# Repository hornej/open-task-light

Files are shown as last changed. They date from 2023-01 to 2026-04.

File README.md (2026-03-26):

# Open Task Light

Open Task Light is an ESP32-S3 task light project with firmware in
`code/open-task-light/` and hardware reference files at the repo root.

The current native firmware supports:
- capacitive touch controls for power, brightness, and color temperature
- separate warm and cool LED channels
- a WS2812 status LED
- optional LD2410B presence sensing
- optional Wi-Fi with native Home Assistant MQTT integration
- optional Apple Home support through native HomeKit
- optional Wi-Fi/SNTP-driven circadian color temperature control

The repo is organized as a top-level project folder with the firmware living
under `code/open-task-light/` and the hardware reference files at the root.

## Repo Layout

- `code/open-task-light/` firmware project
- `pcb/` PCB PDFs and fabrication reference files
- `LICENSE` project license

## Firmware

The active firmware project is in `code/open-task-light/`.

That subproject currently includes:
- ESP-IDF native firmware
- ESPHome configuration
- Arduino sketches
- checked-in defaults in `sdkconfig.defaults`

The ESP-IDF path is the main day-to-day firmware now. It defaults to an
offline local-light build. Wi-Fi, MQTT, HomeKit, and circadian are all
optional compile-time features.

Start with the detailed firmware README here:
- `code/open-task-light/README.md`

For local build profile notes, see:
- `code/open-task-light/local-config-profiles.md`

## Hardware Files

The `pcb/` folder currently contains:
- `DIYson.PDF`
- `DIYson_Fab.PDF`
- `Bill of Materials-DIYson.csv`

These are the board reference and fabrication outputs for the light.

For current build details and project updates, see the Basement Labs page:
- <https://www.basementlabs.net/open-task-light-2>

## Getting Started

If you are working on firmware:

```sh
cd code/open-task-light
```

Then follow the build and setup instructions in `code/open-task-light/README.md`.

Local build outputs such as `build/` and `sdkconfig` are generated there and
are intentionally not tracked in Git.

If you are working on hardware:
- review the PDFs in `pcb/`
- use the Basement Labs page for the current parts/build reference
- keep firmware pin mappings aligned with the board wiring

## Notes

The repo-root README is intentionally a project index. The detailed
day-to-day instructions for building, configuring, and using the embedded code
live in the nested firmware README.

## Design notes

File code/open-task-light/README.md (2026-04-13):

# Open Task Light

Firmware and configs for Open Task Light: an ESP32-S3 task light with
capacitive touch controls, warm/cool PWM channels, a WS2812 status LED, and
optional LD2410B presence sensing.

There are three supported build paths in this repo:
- ESP-IDF native firmware
- ESPHome configuration
- Arduino standalone sketch

The ESP-IDF firmware is the primary implementation and has the most complete
feature set.

## What The Light Does

Hardware and local behavior:
- 5 capacitive touch pads: power, brightness up, brightness down, cooler, warmer
- 2 PWM LED channels: warm white and cool white
- WS2812 status LED
- optional LD2410B presence sensor
- ambient light sensor
- LED NTC temperature sensor
- ESP32-S3 internal temperature monitoring

Optional connected behavior in the native firmware:
- shared Wi-Fi station support
- Home Assistant via native MQTT discovery
- Apple Home via native HomeKit
- Wi-Fi + SNTP circadian color temperature schedule

## Using The Light

### Touch controls

- Power pad:
  - tap toggles the light on or off
  - if the light is off, pressing power turns it on immediately
  - if you keep holding the power pad for about 3 seconds while turning on,
    the WS2812 status LED is enabled for that on-cycle
- Brightness up pad:
  - single tap raises brightness by 1%
  - double tap jumps to max brightness
  - hold ramps brightness upward smoothly
- Brightness down pad:
  - single tap lowers brightness by 1%
  - double tap jumps to the normal minimum brightness
  - hold ramps brightness downward
  - if you want the deepest dim range below the normal minimum, release and
    hold dim-down again after reaching minimum
- Cooler pad:
  - single tap shifts color temperature cooler
  - double tap jumps to maximum cool
  - hold ramps cooler
- Warmer pad:
  - single tap shifts color temperature warmer
  - double tap jumps to maximum warm
  - hold ramps warmer

### Presence behavior

If the LD2410B presence sensor is installed and enabled:
- occupancy turns on only after continuous presence for the configured on delay
- occupancy turns off only after continuous absence for the configured timeout
  (120 seconds by default)
- when occupancy clears, the light fades out
- when occupancy returns, the light fades back to its previous state

### Thermal behavior

- LED NTC temperature can clamp the maximum allowed brightness
- ESP32-S3 internal temperature is monitored separately as a chip-side failsafe
- the LED thermal limit is runtime-adjustable from Home Assistant when MQTT is enabled

## ESP-IDF Native Firmware

Source: `main/otl_main.c`

Quick start:

```sh
idf.py set-target esp32s3
idf.py menuconfig
idf.py build
idf.py -p PORT flash monitor
```

Checked-in defaults live in `sdkconfig.defaults`. Your `menuconfig` changes are
written to the local `sdkconfig` file, which is intentionally ignored so
Wi-Fi credentials and other machine-specific settings stay out of Git.

Default behavior:
- `sdkconfig.defaults` is an offline baseline
- Wi-Fi is off by default
- Home Assistant MQTT is off by default
- HomeKit is off by default
- circadian is off by default

That means a default build stays simple and local-only unless you explicitly
turn connected features on.

### Menuconfig areas

Under `Open Task Light`, the important sections are:

- `Serial logging`
  - app logs, periodic status, touch logs, calibration logs, PWM logs
- `Connectivity`
  - `Enable WiFi`
  - `Enable Home Assistant via MQTT`
  - `Enable Apple Home via HomeKit`
- `Presence sensor`
  - LD2410B enable, optional first-boot Bluetooth disable, distance thresholds,
    on/off delay, polling interval, UART sample stale timeout, UART
    auto-recovery interval
- `PWM`
  - non-overlapping warm/cool PWM
- `Circadian lighting`
  - Wi-Fi/SNTP-based circadian schedule and compile-time defaults

### Connectivity

The native firmware uses a shared Wi-Fi subsystem in `components/otl_net/`.
MQTT, HomeKit, and circadian all sit on top of that and are only compiled when
enabled.

Wi-Fi notes:
- Wi-Fi credentials are compile-time settings in `menuconfig`
- MQTT and HomeKit wait for Wi-Fi to connect before starting
- if Wi-Fi is disabled, none of the network stacks are initialized

### Home Assistant via MQTT

Enable in `menuconfig`:
- `Enable WiFi`
- `Enable Home Assistant via MQTT`

Then set:
- `MQTT broker URI`
- `MQTT username` and `MQTT password` if your broker requires auth
- optional discovery prefix, topic base, and device name

The firmware publishes a native Home Assistant MQTT device with:

- light entity
  - on/off
  - brightness
  - color temperature
- occupancy binary sensor when presence is enabled
- telemetry and diagnostics
  - radar OUT pin state
  - radar UART state
  - ambient lux
  - LED NTC temperature
  - ESP32-S3 internal temperature
  - thermal max brightness cap
  - thermal-limited status
  - Wi-Fi RSSI
  - last event
- runtime controls
  - LED thermal limit
  - radar occupancy off timeout
  - circadian lighting enable
  - circadian lighting coolest time
  - circadian lighting warmest time
  - circadian morning ramp duration
  - verbose diagnostics

Important behavior:
- the light state stays synchronized across touch, MQTT, presence behavior, and
  HomeKit when multiple integrations are enabled
- circadian lighting is runtime-toggleable from Home Assistant so it does not
  have to fight Adaptive Lighting or your own automations
- when the LD2410 UART stream goes stale, the radar presence/motion entities
  are marked unavailable in Home Assistant instead of falsely reading clear,
  while the radar UART diagnostic sensor reports `stale` or `no_response`
- the raw `Radar OUT` entity is published separately for Home Assistant
  visibility, but it is not used for the light auto-off logic
- the MQTT integration also publishes a structured event stream and a `Last Event`
  text sensor instead of mirroring raw serial logs

### Apple Home via HomeKit

Enable in `menuconfig`:
- `Enable WiFi`
- `Enable Apple Home via HomeKit`

Then set:
- `Accessory name`
- `Setup code`
- `Setup ID`

Pairing flow:
1. enter Wi-Fi credentials in `menuconfig`
2. build and flash the firmware
3. boot the light onto Wi-Fi
4. pair it in Apple Home using the configured setup code

Default development values:
- setup code: `111-22-333`
- setup ID: `OTL1`

Change those before handing a build to anyone else.

Current HomeKit surface:
- Lightbulb service
  - on/off
  - brightness
  - color temperature
- Occupancy Sensor service when presence is enabled

HomeKit intentionally stays narrower than Home Assistant. Diagnostics and
runtime tuning are exposed through MQTT/HA, not Apple Home.

### Circadian lighting

Enable in `menuconfig`:
- `Enable WiFi`
- `Enable circadian color temperature (WiFi + SNTP)`

Compile-time circadian settings:
- `Timezone (POSIX TZ string)`
- `SNTP server`
- `Update interval`
- `Coolest time (HH:MM)`
- `Warmest time (HH:MM)`
- `Morning cool ramp duration (minutes)`
- `Minimum cool ratio (%)`
- `Maximum cool ratio (%)`

Runtime behavior:
- the circadian engine computes a base warm/cool mix across the day
- after the warmest time, the light can hold maximum warmth overnight and only
  start cooling during the configurable morning ramp window before the coolest
  time
- temperature touch controls act as a user offset on top of that base
- if MQTT is enabled, Home Assistant can turn circadian lighting on or off at runtime
- if you want Home Assistant to own color temperature policy, disable circadian
  lighting and use your own automations or Adaptive Lighting

## Local Configuration Profiles

If you keep local config fragments outside Git, use:

```sh
./tools/use-local-profile.sh prod
./tools/use-local-profile.sh debug
```

That rebuilds `sdkconfig` from:
1. `sdkconfig.defaults`
2. `sdkconfig.local.shared`
3. `sdkconfig.local.<profile>`

See `local-config-profiles.md` for the expected pattern.

## ESPHome

Config: `esphome/open-task-light.yaml`

Quick start:

```sh
cp esphome/secrets.example.yaml esphome/secrets.yaml
esphome run esphome/open-task-light.yaml
```

Notes:
- `esphome/secrets.yaml` is intentionally ignored; keep your real Wi-Fi
  credentials there
- this path still exists for people who want an ESPHome-based build
- the native ESP-IDF firmware is the preferred path if you want the full touch
  behavior implemented in this repo

## Arduino

Sketch: `arduino/otl/otl.ino`

Optional radar test sketch: `arduino/LD2410B.ino`

Quick start:
1. Open `arduino/otl/otl.ino` in the Arduino IDE.
2. Select an ESP32-S3 board and install the `Adafruit NeoPixel` library.
3. Build and upload.

## Default Pin Map

| Function | GPIO | Notes |
| --- | --- | --- |
| Touch power | GPIO7 | T7 |
| Touch brightness up | GPIO8 | T8 |
| Touch brightness down | GPIO9 | T9 |
| Touch temp up | GPIO10 | T10 |
| Touch temp down | GPIO11 | T11 |
| PWM warm | GPIO35 | LEDC |
| PWM cool | GPIO36 | LEDC |
| WS2812 data | GPIO40 | Status LED |
| ALS (ambient light) | GPIO5 | ADC |
| NTC thermistor | GPIO16 | ADC |
| LD2410B OUT | GPIO15 | Alt: GPIO14 |
| LD2410B UART TX | GPIO43 | ESP32 TX -> radar RX |
| LD2410B UART RX | GPIO44 | ESP32 RX <- radar TX |

Adjust pins to match your board wiring as needed.

## Repo Layout

- `arduino/` Arduino sketches
- `components/esp-homekit-sdk/` vendored HomeKit SDK
- `components/otl_circadian/` shared circadian controller
- `components/otl_net/` shared Wi-Fi subsystem
- `esphome/` ESPHome configuration
- `managed_components/` ESP-IDF managed dependencies
- `main/` ESP-IDF firmware
- `sdkconfig.defaults` checked-in ESP-IDF defaults
- `tools/` helper scripts such as the local profile switcher and PWM scope watcher

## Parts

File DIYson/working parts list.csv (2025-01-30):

Part Name | Quantity | Category | Part Number | Link | European supplier | Note | Unit Cost (USD) | Total Cost (USD)
C-Clamp | 1 | Structure/Motion |  | https://amzn.to/3c4k5Et |  | Any small c-clamp will work | $15.10 | $15.10
GT2-2M Timing Belt (By the Foot) | 2 | Structure/Motion |  | https://openbuildspartstore.com/gt2-2m-timing-belt-by-the-foot/?ref=_2E7m4SXRIy8t | https://vslot-poland.com/timing-belt-GT2 |  | $2.49 | $4.98
Horizontal Rail (500mm) | 1 | Structure/Motion |  | https://openbuildspartstore.com/v-slot-20x20-linear-rail/?ref=_2E7m4SXRIy8t | https://vslot-poland.com/en_US/p/Aluminium-profile-2020-V-SLOT-Black-Anodized-250mm/38 |  | $3.29 | $3.29
Vertical Rail (500mm) | 1 | Structure/Motion |  | https://openbuildspartstore.com/v-slot-20x20-linear-rail/?ref=_2E7m4SXRIy8t | https://vslot-poland.com/en_US/p/Aluminium-profile-2020-V-SLOT-Black-Anodized-250mm/38 |  | $3.99 | $3.99
Xtreme Solid V Wheel Kit | 6 | Structure/Motion |  | https://openbuildspartstore.com/xtreme-solid-v-wheel-kit/?ref=_2E7m4SXRIy8t | https://vslot-poland.com/xtreme-solid-v-wheel-kit | Black Delrin or V-wheel kits can be substituted | $6.99 | $41.94
LED | 1 | Lighting | BXRV-TR-2750G-20A0-A-23 | https://www.digikey.com/en/products/detail/bridgelux/BXRV-TR-2750G-20A0-A-23/10279858 |  |  | $5.60 | $5.60
LED Holder | 1 | Lighting | 492 TYP L8 | https://led.cdiweb.com/products/detail/492typl8-bender-wirth/636069/
LED Socket | 1 | Lighting | C16142_HEKLA-SOCKET-K | https://www.mouser.com/ProductDetail/928-HEKLA16142 |  |  | $1.37 | $1.37
Lens | 1 | Lighting | CP16109_CARMEN-50-W-C | https://www.mouser.com/ProductDetail/928-CP16109 | https://eu.mouser.com/ProductDetail/928-CP16109 | Don't drop this, the tabs will break! | $4.98 | $4.98
48V AC/DC Power Supply | 1 | Lighting | SDI24-48-UD-P5 | https://www.mouser.com/ProductDetail/490-SDI24-48-UD-P5 |  |  | $18.94 | $18.94
AC Power Cord (US) | 1 | Lighting | Schurter 6010.5274 | https://www.mouser.com/ProductDetail/693-6010.5274
M3 10mm Standoffs | 2 |  |  | https://a.co/d/4ye4oMW
Heatpipe | 1 | Cooling | ATS-HP-F6L200S23W-294 | https://www.mouser.com/ProductDetail/984-HPF5L300S13W236 |  |  | $14.02 | $14.02
6mm Idler Pulley (Pack of 10) | 1 | Hardware |  | https://amzn.to/3AthhKy | https://nl.aliexpress.com/item/1005004778728908.html?mp=1 |  | $11.99 | $11.99
Aluminum Spacers (40mm) (Pack of 10) | 1 | Hardware |  | https://openbuildspartstore.com/aluminum-spacers-10-pack/?ref=_2E7m4SXRIy8t | https://nl.aliexpress.com/item/10000404234974.html?mp=1 | Connects vertical rail to base | $7.89 | $7.89
Aluminum Spacers (6mm) (Pack of 10) | 1 | Hardware |  | https://openbuildspartstore.com/aluminum-spacers-10-pack/?ref=_2E7m4SXRIy8t | https://nl.aliexpress.com/item/10000404234974.html?mp=1 | Four needed for mounting wheels | $3.39 | $3.39
Assorted metric screws and nuts | 1 | Hardware |  | https://amzn.to/3camT2N | https://nl.aliexpress.com/item/33033655207.html?mp=1 | Used to secure belt clips and pulleys (don't get this unless you need the m2 and m3 screws, it's one of the most expensive items on the list) | $32.98 | $32.98
Black-Oxide Alloy Steel Hex Drive Flat Head Screw | 1 | Hardware |  | https://www.mcmaster.com/91294A002/ |  | Used to secure drag chain and strain relief clip | $8.75 | $8.75
Black-Oxide 18-8 Stainless Steel Pan Head Phillips Screws | 1 | Hardware |  | https://www.mcmaster.com/95836A277/ |  | Used to attach PCB to LED cover | $10.52 | $10.52
Eccentric Spacer (6mm) | 2 | Hardware |  | https://openbuildspartstore.com/eccentric-spacer/?ref=_2E7m4SXRIy8t |  |  | $1.99 | $3.98
Low Profile M5 Screws (15mm) (Pack of 10) | 1 | Hardware |  | https://openbuildspartstore.com/low-profile-screws-m5-10-pack/?ref=_2E7m4SXRIy8t | https://nl.aliexpress.com/item/1005003411992910.html?mp=1 | 4 needed to attach base and pulley assembly to vertical rail. One needed to tension the base | $1.19 | $1.19
Low Profile M5 Screws (25mm) (Pack of 10) | 1 | Hardware |  | https://openbuildspartstore.com/low-profile-screws-m5-10-pack/?ref=_2E7m4SXRIy8t | https://nl.aliexpress.com/item/1005003411992910.html?mp=1 | For mountng wheels to carriage and counterweight | $1.39 | $1.39
Low Profile Screw (Pack of 10) | 1 | Hardware |  | https://www.mcmaster.com/97710A129/ |  | Used to mount the LED assembly to the horizontal arm | $10.00 | $10.00
M3 Nyloc Nuts (Pack of 50) | 1 | Hardware |  | https://amzn.to/3Qxgn5a | https://nl.aliexpress.com/item/33030388407.html?mp=1 | Used in pulley assembly | $6.99 | $6.99
M5 Nyloc Nuts (Pack of 50) | 1 | Hardware |  | https://amzn.to/3T3DINM | https://nl.aliexpress.com/item/33030388407.html?mp=1 | Used in base | $6.49 | $6.49
Super Low Profile Nyloc Nut (pack of 4) | 2 | Hardware |  | https://www.getfpv.com/m5-black-aluminum-shallow-flange-lock-nut-set-of-4-cw.html | https://www.buildyourowndrone.co.uk/lumenier-m5-black-aluminum-low-profile-lock-nut-set-of-4-cw | For mountng wheels to carriage and counterweight | $4.99 | $9.98

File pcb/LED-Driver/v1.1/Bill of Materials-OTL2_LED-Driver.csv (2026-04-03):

Designator | Supplier Part Number | Supplier | Quantity | Comment | Manufacturer | Manufacturer Part Number | Footprint | Description | Case/Package
C7 | C185774 | LCSC | 1 | 10uF | TORCH | CA45-A-16V-10µF-K | CAPMP3216X180N | 10uF 16V 2O@100kHz ±10% CASE-A-3216 Tantalum Capacitors ROHS
C15 | C15195 | LCSC | 1 | 10nF | Samsung Electro-Mechanics | CL05B103KB5NNNC | CAP_0402_SK | 50V 10nF X7R ±10% 0402 Multilayer Ceramic Capacitors MLCC - SMD/SMT ROHS | 0402
C18 | C28233 | LCSC | 1 | 100nF | Samsung Electro-Mechanics | CL21B104KCFNNNE | CAP_0805_SK | 100V 100nF X7R ±10% 0805 Multilayer Ceramic Capacitors MLCC - SMD/SMT ROHS | 0805
C23 | C19702 | LCSC | 1 | 10uF | Samsung Electro-Mechanics | CL10A106KP8NNNC | CAP_0603_SK | 10V 10uF X5R ±10% 0603 Multilayer Ceramic Capacitors MLCC - SMD/SMT ROHS | 0603
CONN1 | C5187472 | LCSC | 1 | TYPE-C 16P QTWT | SHOU HAN | TYPE-C 16P QTWT | CONN_USBC_C5187472 | 3A 1 Surface Mount 16P Female -25?~+85? Type-C SMD USB Connectors ROHS USB-C
CONN2 |  |  | 1 | 781710002 | Molex | 78171-0002 | MOLEX_0781710002 | Pico-EZmate Wire-to-Board Header Vertical Housing Height 1.55mm with Side Friction Locks 2 Circuits
CONN3 | C5852764 | LCSC | 1 | 009276004021106 | KYOCERA AVX | 009276004021106 | CONN_009276004021006_AVX | Rectangular Power Connector, 4 Contact(s), Female, Surface Mount Terminal
CONN4 | C724177 | LCSC | 1 | Pico-EZmate | Molex | 78171-0005 | CONN_781710000-SD_05_MOL | Pico-EZmate Wire-to-Board Header Vertical Housing Height 1.55mm with Side Friction Locks 5 Circuits
D8 | C134996 | LCSC | 1 | 54V | Diodes | SMAJ54A-13-F | DIOD-SMA-2_V | SMAJ Series 54 V 400 W Surface Mount Uni-Directional TVS Diode - DO-214AC | SMA
L3 | C92942 | LCSC | 1 | 33uH | Taiyo Yuden | NR6045T330M | NR6045 | FIXED IND 33UH 1.4A 188.5 MOHM | Nonstandard
R5 | C144804 | LCSC | 1 | 118k | Yageo | AC0402FR-07118KL | RES_0402 | Res Thick Film 0402 118K Ohm 1% 0.063W(1/16W) ±100ppm/C Pad SMD Automotive T/R | 0402
R6 | C163478 | LCSC | 1 | 22.1k | Yageo | RC0402FR-0722K1L | RES_0402 | SMD Chip Resistor, 22.1 kOhm, ï¿½ 1%, 62.5 mW, 0402 [1005 Metric], Thick Film, General Purpose | 0402
R15 | C26083 | LCSC | 1 | 1M | Uni-Royal | 0402WGF1004TCE | RES_0402 | Res Thick Film 0402 1M Ohm 1% 0.063W(1/16W) ±100ppm/C Pad SMD T/R
R24 | C25764 | LCSC | 1 | 200k | Royal Ohm | 0402WGF2003TCE | RES_0402 | Royal Ohm 0402WGF2003TCE 200K 1% 1/16W 0402 Thick Film Chip Resistor
R25 | C17888 | LCSC | 1 | 0 | Royal Ohm | 1206W4F0000T5E | RES_1206 | Thick Film Resistors - SMD RMC 1206 1/4W 1% T/R-5000
R31 | C25897 | LCSC | 1 | 49.9k | Royal Ohm | 0402WGF4992TCE | RES_0402 | Thick Film Resistors - SMD RMC 0402 1/16W 1% T/R-10000
R32 | C11457 | LCSC | 1 | 3.24k | Royal Ohm | 0402WGF3241TCE | RES_0402 | Thick Film Resistors - SMD RMC 0402 1/16W 1% T/R-10000
R34 | C23254 | LCSC | 1 | 82k | Royal Ohm | 0603WAF8202T5E | RES_0603 | -55?~+155? 100mW 75V 82kO Thick Film Resistor ±1% ±100ppm/? 0603 Chip Resistor - Surface Mount ROHS
R37 | C11702 | LCSC | 1 | 1k | Royal Ohm | 0402WGF1001TCE | RES_0402 | 62.5mW Thick Film Resistors 50V ±100ppm/? ±1% 1kO 0402 Chip Resistor - Surface Mount ROHS
U1 | C3013941 | LCSC | 1 | ESP32-S3-MINI-1-N4R2 | Espressif Systems | ESP32-S3-MINI-1-N4R2 | ESP32-S3-MINI-1-N4R2_noVias | On-board PCB antenna SMD WiFi Modules ROHS
U4 | C21260865 | LCSC | 1 | LMR51606XDBVR | Texas Instruments | LMR51606XDBVR | SOT-23-6 | SIMPLE SWITCHER® power converter with 4.5V-to-65V 0.6A synchronous buck and 25µA quiescent current 6-SOT-23 -40 to 150 | SOT-23
U5 | C6186 | LCSC | 1 | AMS1117-3.3_AMS | Advanced Monolithic Systems | AMS1117-3.3 | DCY0004A_L | -40?~+125? 0.003%Vout 1 1.1V@(800mA) 16V 1A 3.3V 5mA 72dB@(120Hz) Fixed Over Current Protection?Over Temperature Protection Positive SOT-223 Voltage Regulators - Linear, Low Drop Out (LDO) Regulators ROHS
U6 |  |  | 1 | ALS-PT19-315C/L177/TR8 | Everlight | ALS-PT19-315C/L177/TR8 | XDCR_ALS-PT19-315C/L177/TR8 | Light to Current Ambient Light Sensor Digital 3.3V/5V 2-Pin SMD T/R | SMD/SMT
U7 | C168856 | LCSC | 1 | 74LVC1T45W6-7 | Diodes | 74LVC1T45W6-7 | SOT-23-6 | 74LVC Series 5.5 V 3-State SMT Single Bit Dual Supply Transceiver - SOT-26 | SOT-23-6
U8 | C965557 | LCSC | 1 | WS2812B-4020 | Worldsemi | WS2812B-4020 | WS2812B-4020 | SMD,2x4mm RGB LEDs(Built-in IC) ROHS
C19, C20 | C513710 | LCSC | 2 | 220nF | Yageo | CC0805KKX7R0BB224 | CAP_0805_SK | CAP CER 0.22UF 100V X7R 0805 | 0805
CONN5, CONN6 |  |  | 2 | 781710002 | Molex | 78171-0002 | MOLEX_0781710002_HANDSOLDER_NTC | Pico-EZmate Wire-to-Board Header Vertical Housing Height 1.55mm with Side Friction Locks 2 Circuits
L1, L2 | C5291902 | LCSC | 2 | 120uH | CENKER | CKCS8040-120uH/M | IND_8x8x4 | 950mA 120uH 334mO 1.12A Magnetic Shielded Inductor ±20% SMD,8x8mm Fixed Inductors RoHS
R1, R3 | C25889 | LCSC | 2 | 3.01k | Royal Ohm | 0402WGF3011TCE | RES_0402 | Thick Film Resistors - SMD RMC 0402 1/16W 1% T/R-10000
R2, R4 | C25765 | LCSC | 2 | 20k | UNI-ROYAL | 0402WGF2002TCE | RES_0402 | 20kO ±1% 62.5mW 0402 Thick Film Resistor
R13, R14 | C25905 | LCSC | 2 | 5.1k | Uni-Royal | 0402WGF5101TCE | RES_0402 | Res Thick Film 0402 5.1K Ohm 1% 0.063W(1/16W) ±100ppm/C Pad SMD T/R
R28, R29 | C858641 | LCSC | 2 | 0.1 | Yageo Group | PT0603FR-7W0R1L | RES_0603 | Res Thick Film 0603 0.1 Ohm 1% 0.2W(1/5W) ±200ppm/C Pad SMD Automotive T/R | 0603
SW8, SW9 | C393942 | LCSC | 2 | TS24CA | SHOU HAN | TS24CA | SW_TS24CA | 1.8mm 3.5mm Rectangle button 50mA Horizontal attachment 4.55mm SPST 12V SMD Tactile Switches ROHS spst
U2, U3 | C114277 | LCSC | 2 | TPS92511DDAR | Texas Instruments | TPS92511DDAR | VREG_LM5017MR/NOPB | 500mA 30W Anode Capable constant current buck LED Dvr 8-SO PowerPAD -40 to 125 | HSOP
C1, C3, C5 | C237304 | LCSC | 3 | 4.7uF | Murata | GRM31CC72A475KE11L | CAP_1206_SK | 100V 4.7uF X7S ±10% 1206 Multilayer Ceramic Capacitors MLCC - SMD/SMT ROHS | 1206
C8, C9, C11 | C45783, C98190 | LCSC | 3 | 22uF | Samsung Electro-Mechanics, Samsung | CL21A226MAQNNNE, CL21A226MOQNNNE | CAP_0805_SK | Multilayer Ceramic Capacitor, 22 uF, 25 V, ± 20%, X5R, 0805 [2012 Metric], Cap Ceramic 22uF 16V X5R 20% SMD 0805 85°C Embossed Plastic T/R | 0805
D1, D2, D3 | C77393 | LCSC | 3 | SS2PH10-M3/84A | Vishay | SS2PH10-M3/84A | DIOD_DO-220AA (SMP) | Rectifier Diode, Schottky, 1 Phase, 1 Element, 2A, 100V V(RRM), Silicon, DO-220AA | DO-220AA
D5, D6, D7 | C5246195 | LCSC | 3 | LESD5D5.0CT1G_Leiditech | Leiditech | LESD5D5.0CT1G | DIOD_SOD523 | ESD DIODE 5VWM 12VC SOD-523 bi-directional
R7, R8, R35 | C25900 | LCSC | 3 | 4.7k | Royal Ohm | 0402WGF4701TCE | RES_0402 | Res Thick Film 0402 4.7K Ohm 1% 0.063W(1/16W) ±100ppm/C Pad SMD T/R
R16, R23, R26, R27 | C137962 | LCSC | 4 | 4.7 | Yageo | RC0402FR-074R7L | RES_0402 | SMD Chip Resistor 4.7 Ohm ½ 1% 62.5 Mw 0402 [1005 Metric] Thick Film General Purpose | 0402
C2, C4, C12, C16, C17 | C52923 | LCSC | 5 | 1uF | Samsung | CL05A105KA5NQNC | CAP_0402_SK | 1 µF ±10% 25V Ceramic Capacitor X5R 0402 (1005 Metric) | 0402
R9, R10, R17, R33, R36 | C25744 | LCSC | 5 | 10k | Uni-Royal | 0402WGF1002TCE | RES_0402 | Res Thick Film 0402 10K Ohm 1% 0.063W(1/16W) ±100ppm/C Pad SMD T/R
R11, R12, R30, R38, R39 | C106231 | LCSC | 5 | 0 | Yageo | RC0402FR-070RL | RES_0402 | Res Thick Film 0402 0 Ohm Molded SMD SMD Paper T/R | 0402
R18, R19, R20, R21, R22 | C276273 | LCSC | 5 | 510 | Yageo | RC0402FR-07510RL | RES_0402 | SMD Chip Resistor, 510 Ohm, ± 1%, 63 mW, 0402 [1005 Metric], Thick Film, General Purpose | 0402
C6, C10, C13, C14, C21, C22 | C1525 | LCSC | 6 | 100nF | Samsung Electro-Mechanics | CL05B104KO5NNNC | CAP_0402_SK | 16V 100nF X7R ±10% 0402 Multilayer Ceramic Capacitors MLCC - SMD/SMT ROHS | 0402

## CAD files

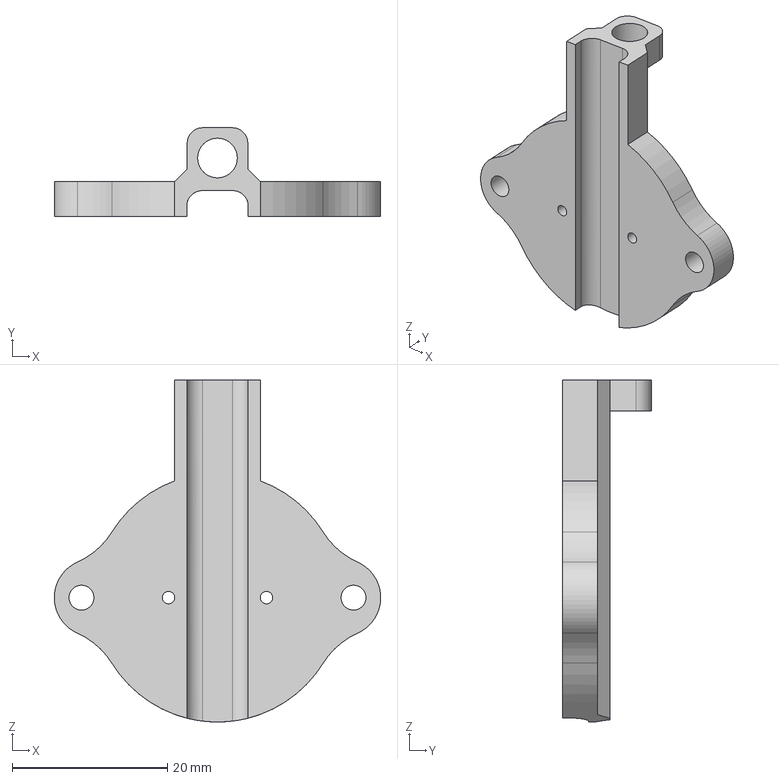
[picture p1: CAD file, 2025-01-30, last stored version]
DIYson/Mechanical/STEP/Lighting Assembly Mount.step
42.0 x 11.4 x 44.0 mm

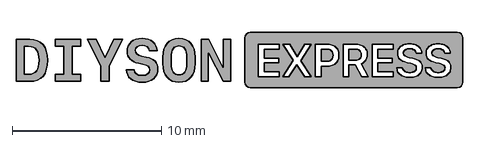
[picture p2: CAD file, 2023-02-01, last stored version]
DIYson Express/Assets/express logo expanded.dxf
29.9 x 3.70 mm

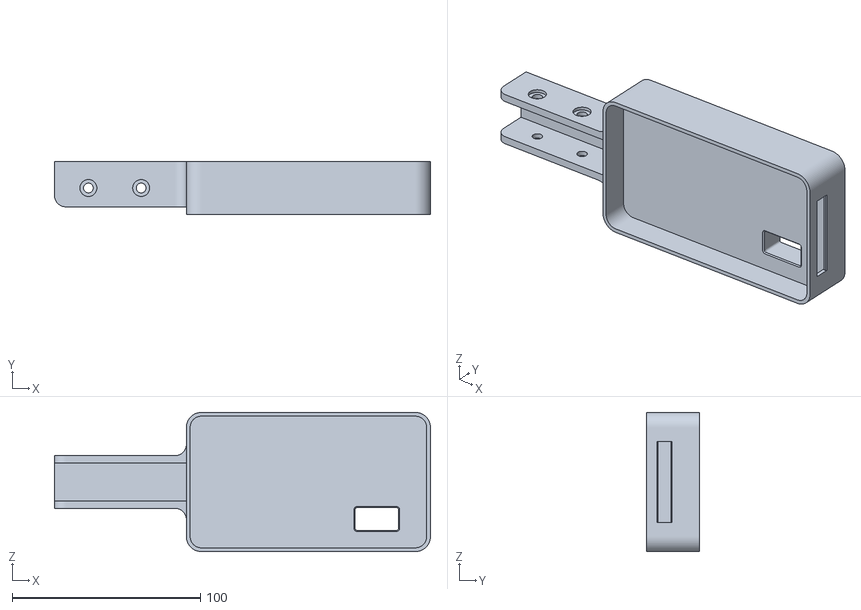
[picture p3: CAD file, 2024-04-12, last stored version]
DIYson Express/Community-Made Alternatives/brukhabtu - LED Holder (LumeCube)/Lume Cube Bicolor Panel.stl
199.6 x 28.0 x 73.9

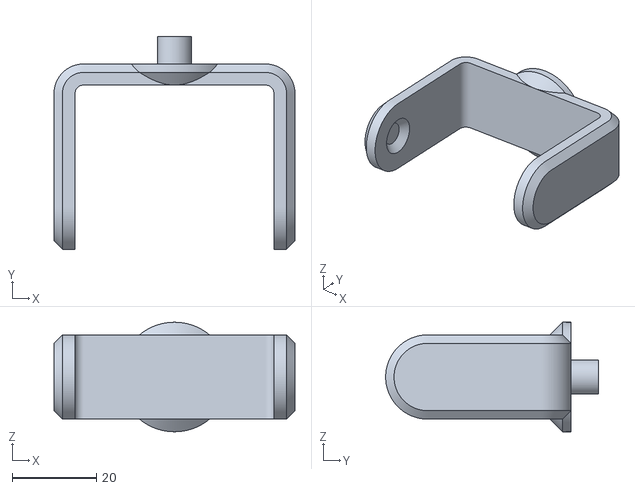
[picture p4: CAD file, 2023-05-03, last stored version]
DIYson Express/Community-Made Alternatives/jfuchs - Gimbal/Outer ring.stl
57.2 x 50.5 x 26.0

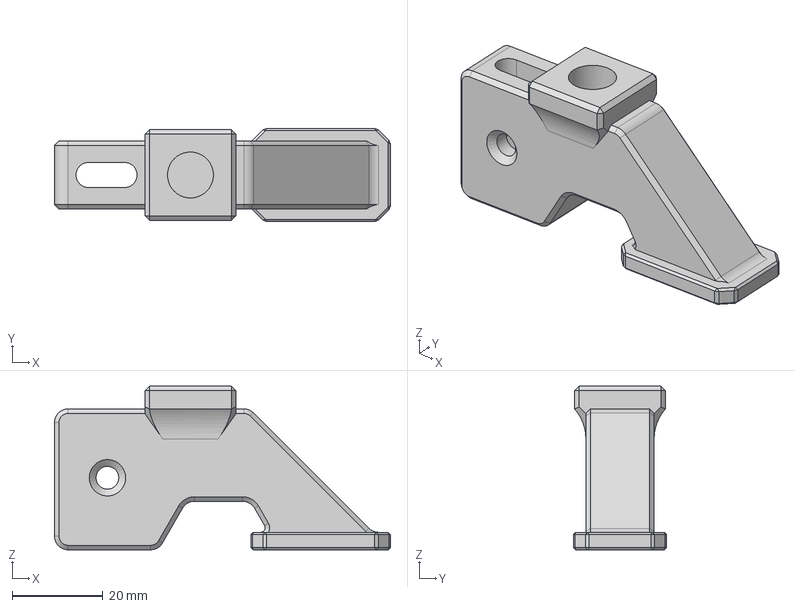
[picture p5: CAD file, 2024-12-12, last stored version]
DIYson Express/Community-Made Alternatives/robocat-studios - Base for IRWIN QUICK-GRIP/Base for IRWIN QUICK-GRIP.step
73.9 x 20.5 x 36.0 mm

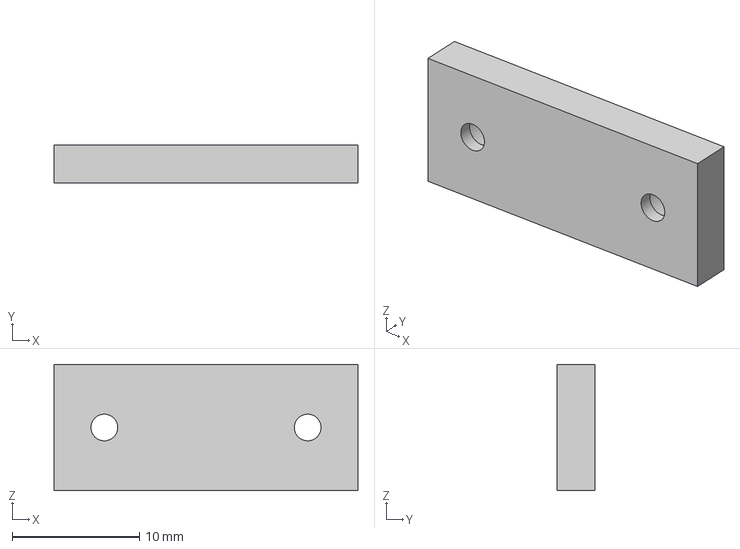
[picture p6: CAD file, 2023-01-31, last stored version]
DIYson Express/Printed Parts/STEP/Coutnterweight Lid.step
23.9 x 3.00 x 9.92 mm

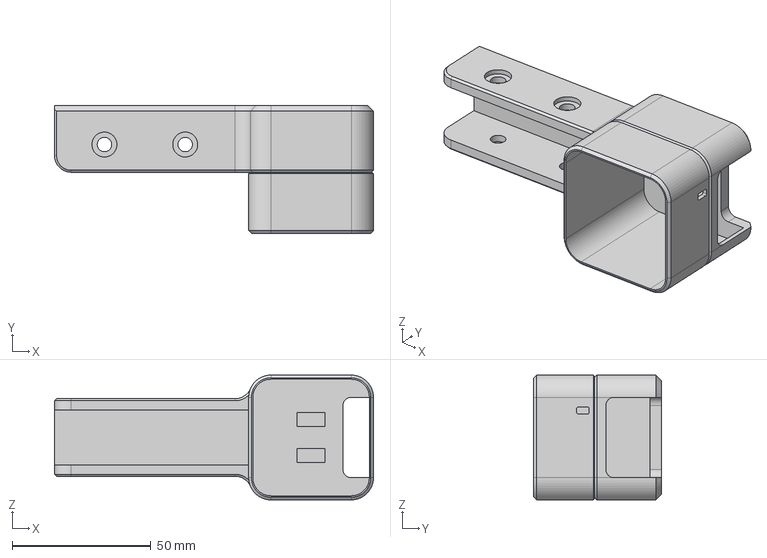
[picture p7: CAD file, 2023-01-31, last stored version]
DIYson Express/Printed Parts/STEP/LED Holder Options/Ulanzi L2.step
115.0 x 46.0 x 45.0 mm

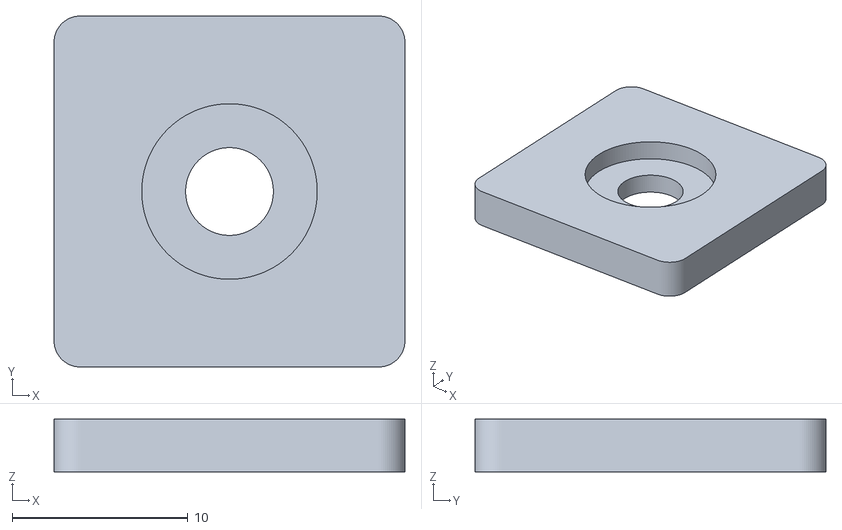
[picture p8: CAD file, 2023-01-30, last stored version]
DIYson Express/Printed Parts/STL/End Cap (optional).stl
20.0 x 20.0 x 3.00

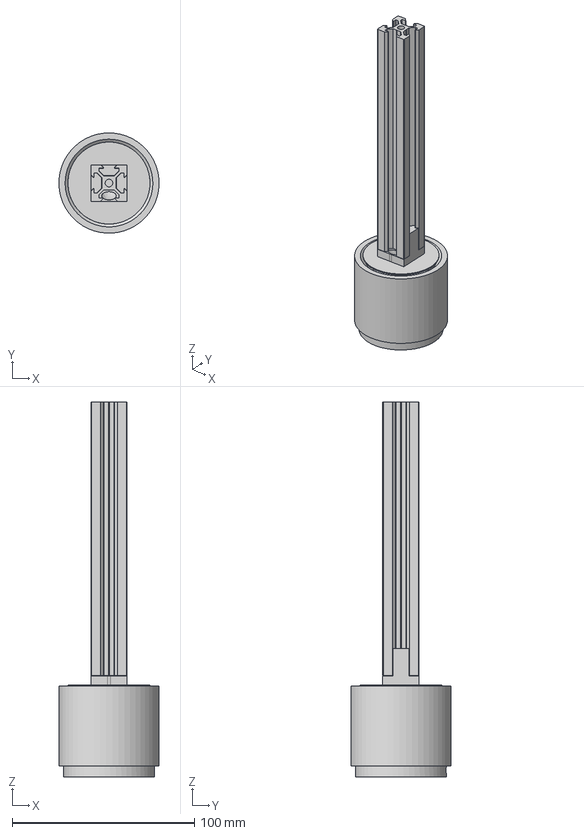
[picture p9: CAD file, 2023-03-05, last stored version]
DIYson/Community-Made Alternatives/Tim - Base/Base.step
55.0 x 55.0 x 205.7 mm
Body_Kugel_einzeln (1) x 8
Body_Innenring (1)
Body_Aussenring (1)
20x20Rail
SlipRing
BoxUpper
BoxLower
Spacer
RailConnector

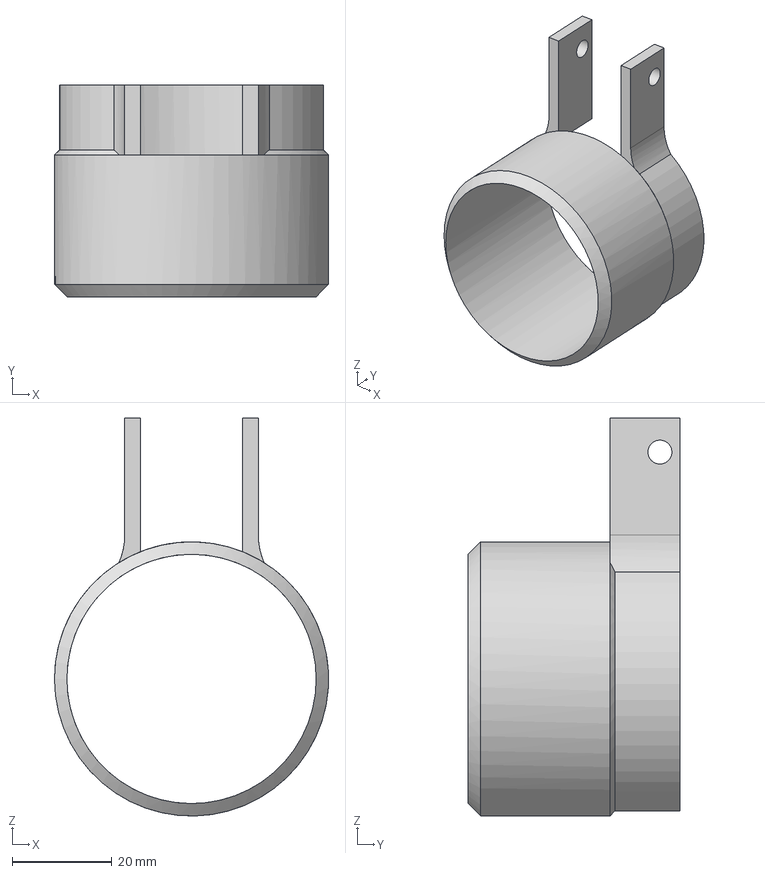
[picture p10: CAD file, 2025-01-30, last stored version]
DIYson/Mechanical/STEP/LED Cover - Bottom.step
55.0 x 42.5 x 79.8 mm

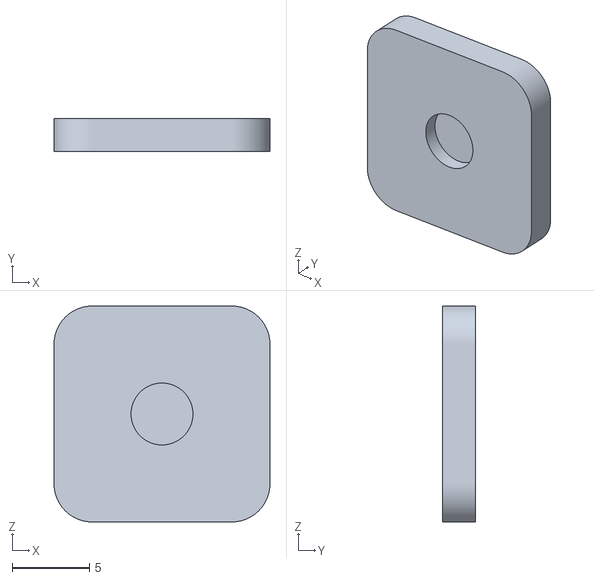
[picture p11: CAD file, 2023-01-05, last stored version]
DIYson/Mechanical/STL/Increase Brightness Button.stl
13.9 x 2.10 x 13.9

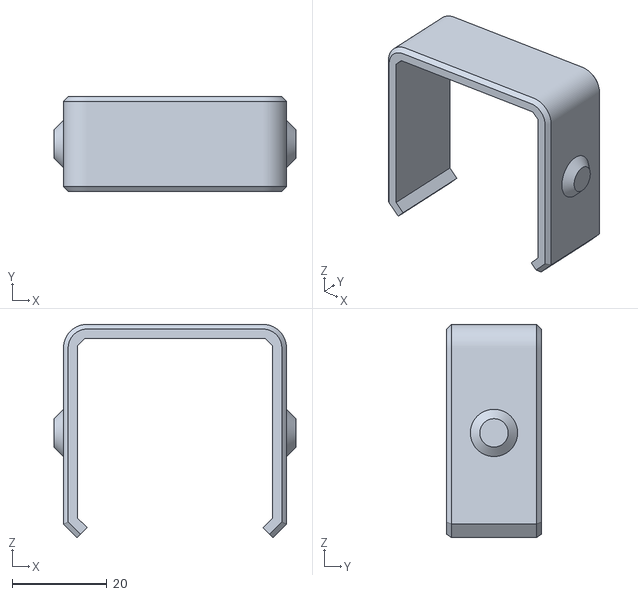
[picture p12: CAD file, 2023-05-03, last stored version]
DIYson Express/Community-Made Alternatives/jfuchs - Gimbal/Inner ring.stl
51.2 x 20.0 x 45.1

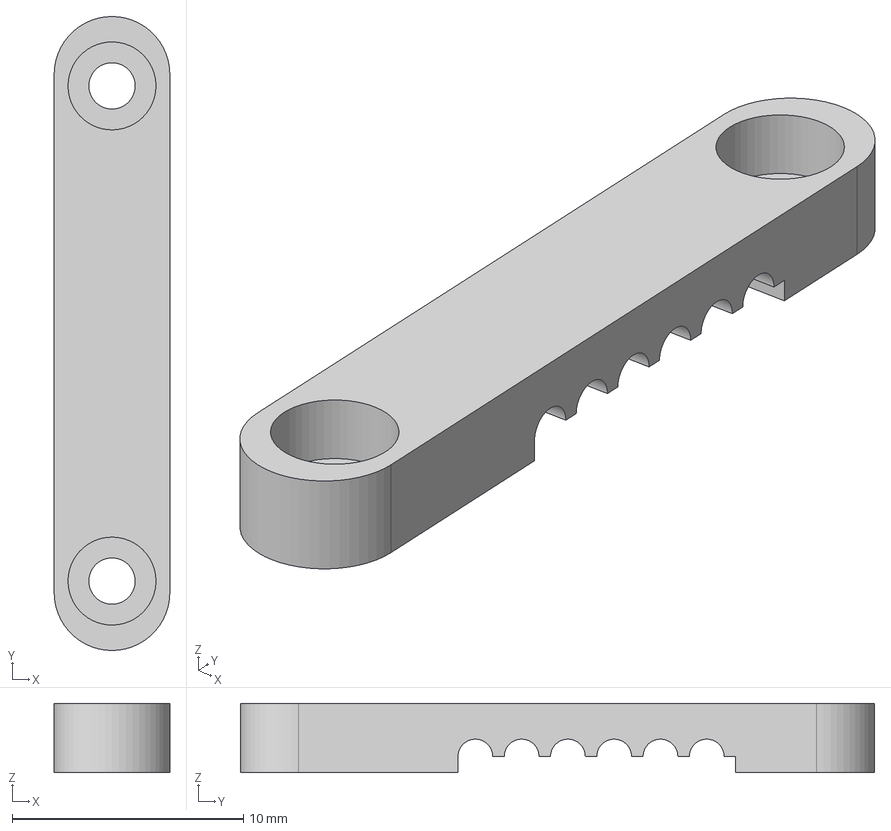
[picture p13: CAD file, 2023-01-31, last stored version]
DIYson Express/Printed Parts/STEP/Carriage Belt Clip.step
5.00 x 27.4 x 3.00 mm

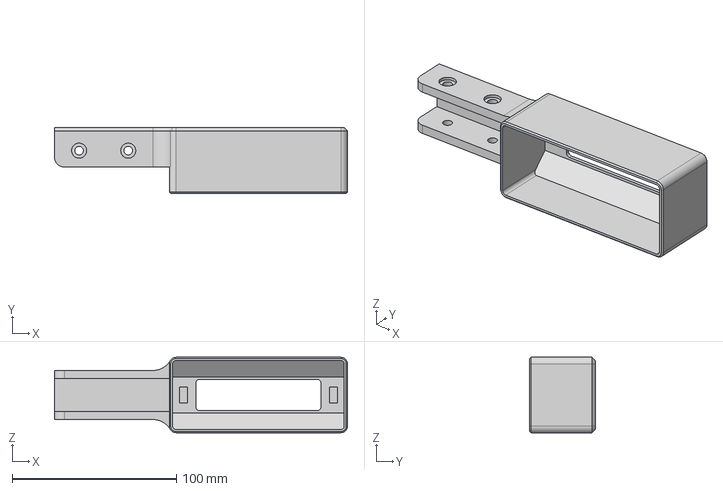
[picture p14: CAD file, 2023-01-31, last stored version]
DIYson Express/Printed Parts/STEP/LED Holder Options/Ulanzi Wand.step
178.5 x 40.0 x 46.0 mm

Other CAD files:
DIYson Express/Community-Made Alternatives/brukhabtu - LED Holder (LumeCube)/LEDHolderLumeCube.step
DIYson Express/Printed Parts/STL/Charging Base (optional).stl
DIYson/Mechanical/STEP/LED Cover - Top.step
DIYson/Mechanical/STL/Decrease Brightness Button.stl
DIYson Express/Community-Made Alternatives/jfuchs - Gimbal/Extrusion bracket.stl
DIYson Express/Community-Made Alternatives/robocat-studios - Base for IRWIN QUICK-GRIP/Base for IRWIN QUICK-GRIP.3mf
DIYson Express/Fan-Made Alternatives/jfuchs - Gimbal/Extrusion bracket.stl
DIYson Express/Printed Parts/F3D/Base.f3d
DIYson Express/Printed Parts/F3D/Desk Mount.f3d
DIYson Express/Printed Parts/F3D/LED Holder Starter Template.f3z
DIYson Express/Printed Parts/STEP/Base.step
DIYson Express/Printed Parts/STEP/Carriage.step
DIYson Express/Printed Parts/STEP/Chargine Base.step
DIYson Express/Printed Parts/STEP/Counterweight Belt Clip.step
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

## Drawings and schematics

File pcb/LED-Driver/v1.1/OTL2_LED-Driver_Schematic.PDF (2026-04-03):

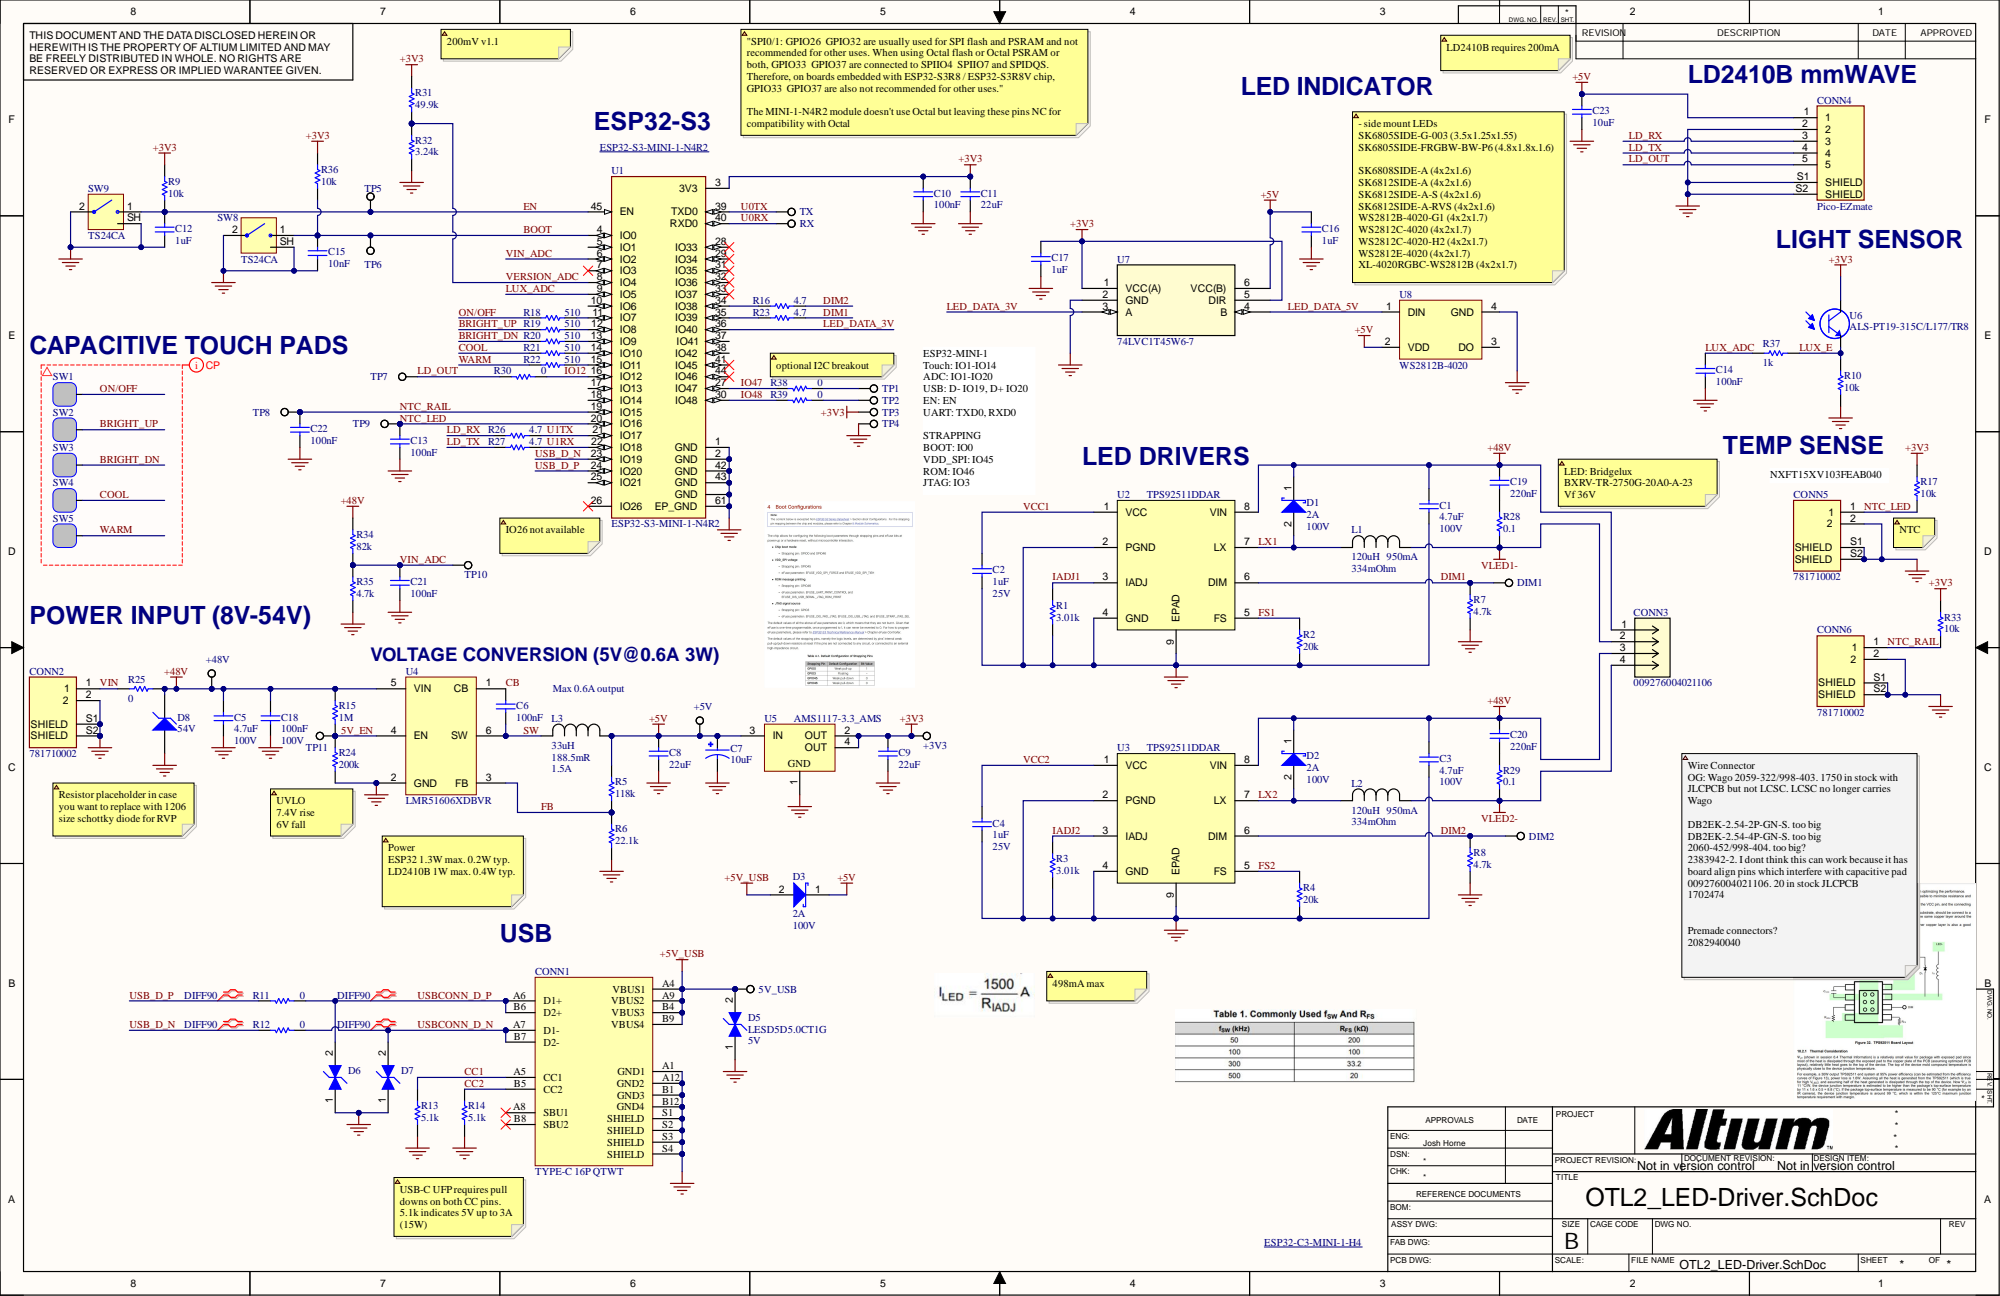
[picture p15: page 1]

DWG . N O . | R E V | * . S H T.

T H IS DOC U MEN T AN D T HE D ATA D ISCLOSED HEREI N OR HEREW I T H IS T HE PROPER TY OF ALT I U M LI M I TED AN D M AY BE F REELY D IST R IBU TED I N W HOLE. NO R IGH TS ARE RESERVED OR EXPRESS OR I MPLIED WARAN TEE GIVEN . | | REVISI O | N DESC R IPT I O N | DAT E | APPR OVED

sed for SPI flas

REV. SHT. DWG. NO.

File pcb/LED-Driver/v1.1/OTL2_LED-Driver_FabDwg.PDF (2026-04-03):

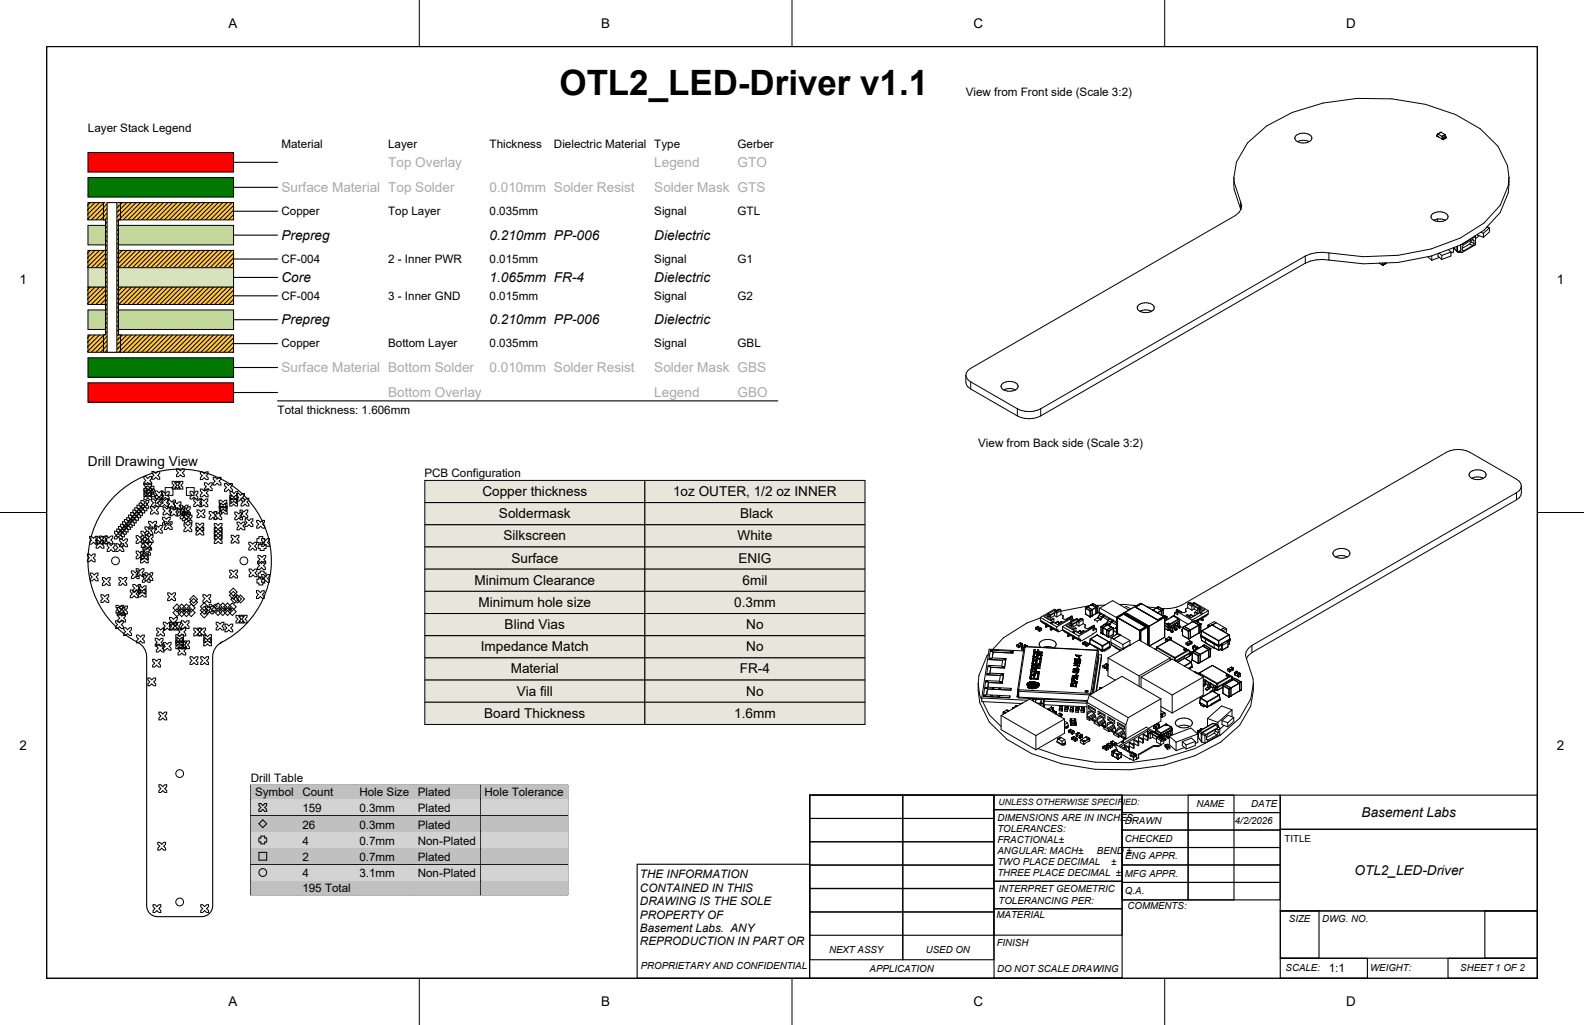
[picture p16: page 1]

View from Front side (Scale 3:2)

View from Back side (Scale 3:2)

UNLESS OTHERWISE SPECIFIED: | | NAME | DATE | Basement Labs
DIMENSIONS ARE IN INCHES TOLERANCES: FRACTIONAL± ANGULAR: MACH± BEND ± TWO PLACE DECIMAL ± THREE PLACE DECIMAL ± | DRAWN | | 4/2/2026

CHECKED | | | TITLE OTL2_LED-Driver
ENG APPR.

THE INFORMATION CONTAINED IN THIS DRAWING IS THE SOLE PROPERTY OF Basement Labs. ANY REPRODUCTION IN PART OR PROPRIETARY AND CONFIDENTIAL | | | MFG APPR.

INTERPRET GEOMETRIC TOLERANCING PER: | Q.A.

MATERIAL | | SIZE | DWG. NO.

NEXT ASSY | USED ON | FINISH DO NOT SCALE DRAWING

APPLICATION | | | 1:1

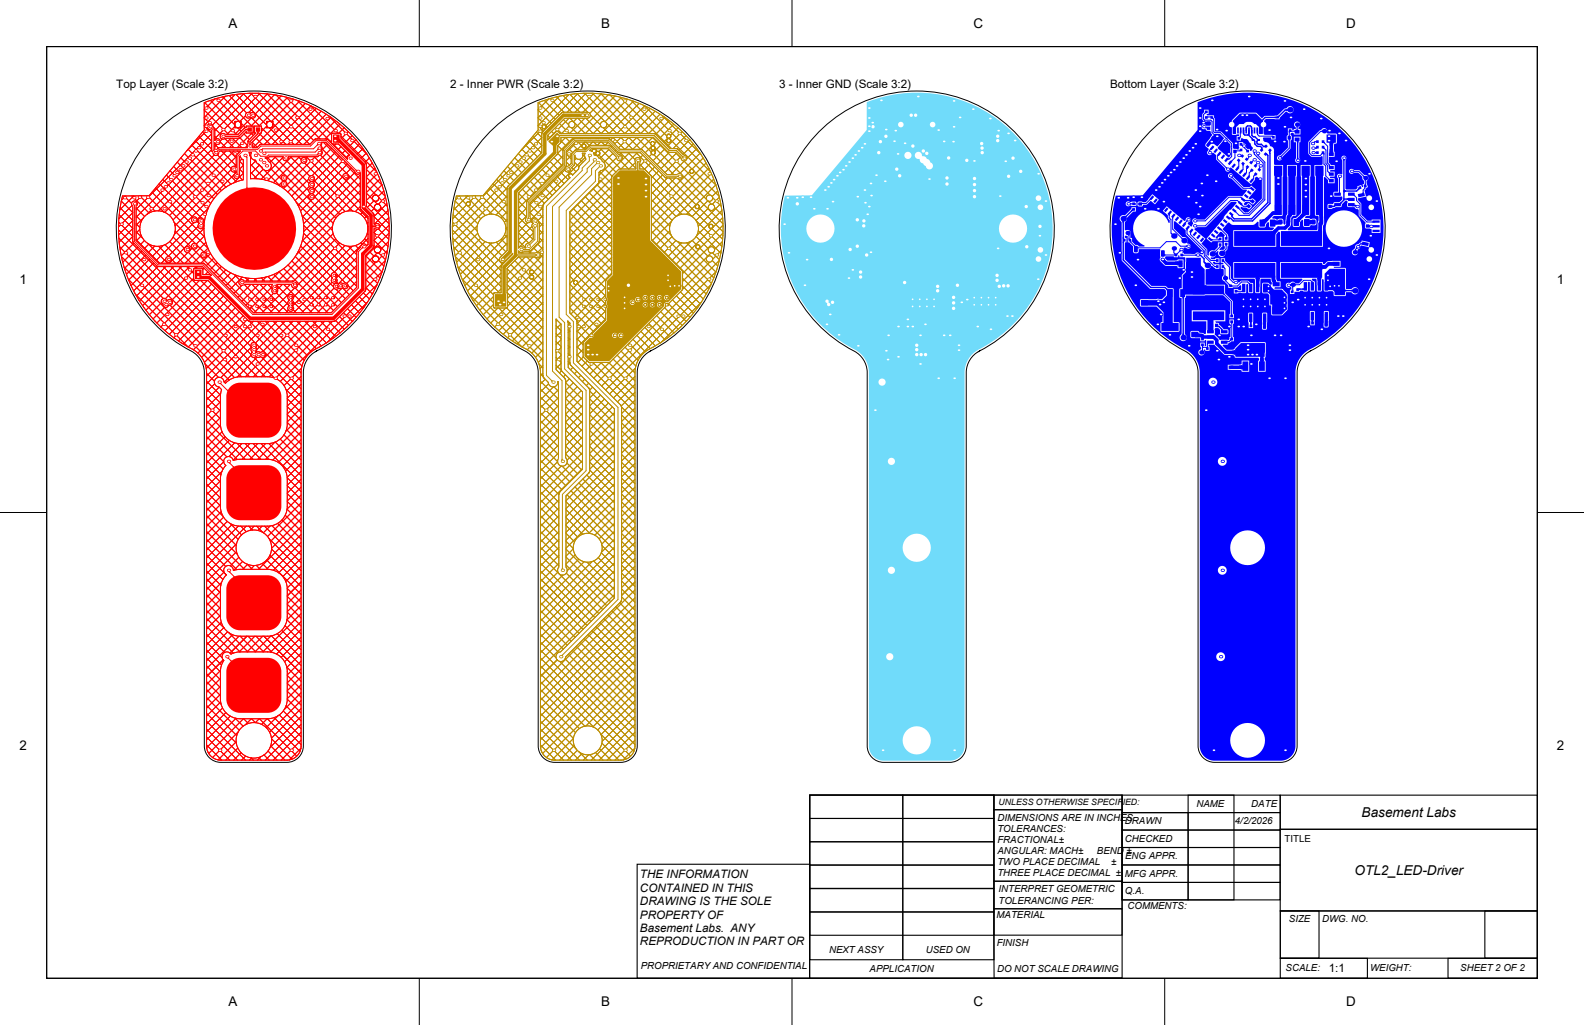
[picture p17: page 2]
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

CHECKED | | | TITLE OTL2_LED-Driver
ENG APPR.

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

INTERPRET GEOMETRIC TOLERANCING PER: | Q.A.

MATERIAL | | SIZE | DWG. NO.

NEXT ASSY | USED ON | FINISH DO NOT SCALE DRAWING

APPLICATION | | | 1:1

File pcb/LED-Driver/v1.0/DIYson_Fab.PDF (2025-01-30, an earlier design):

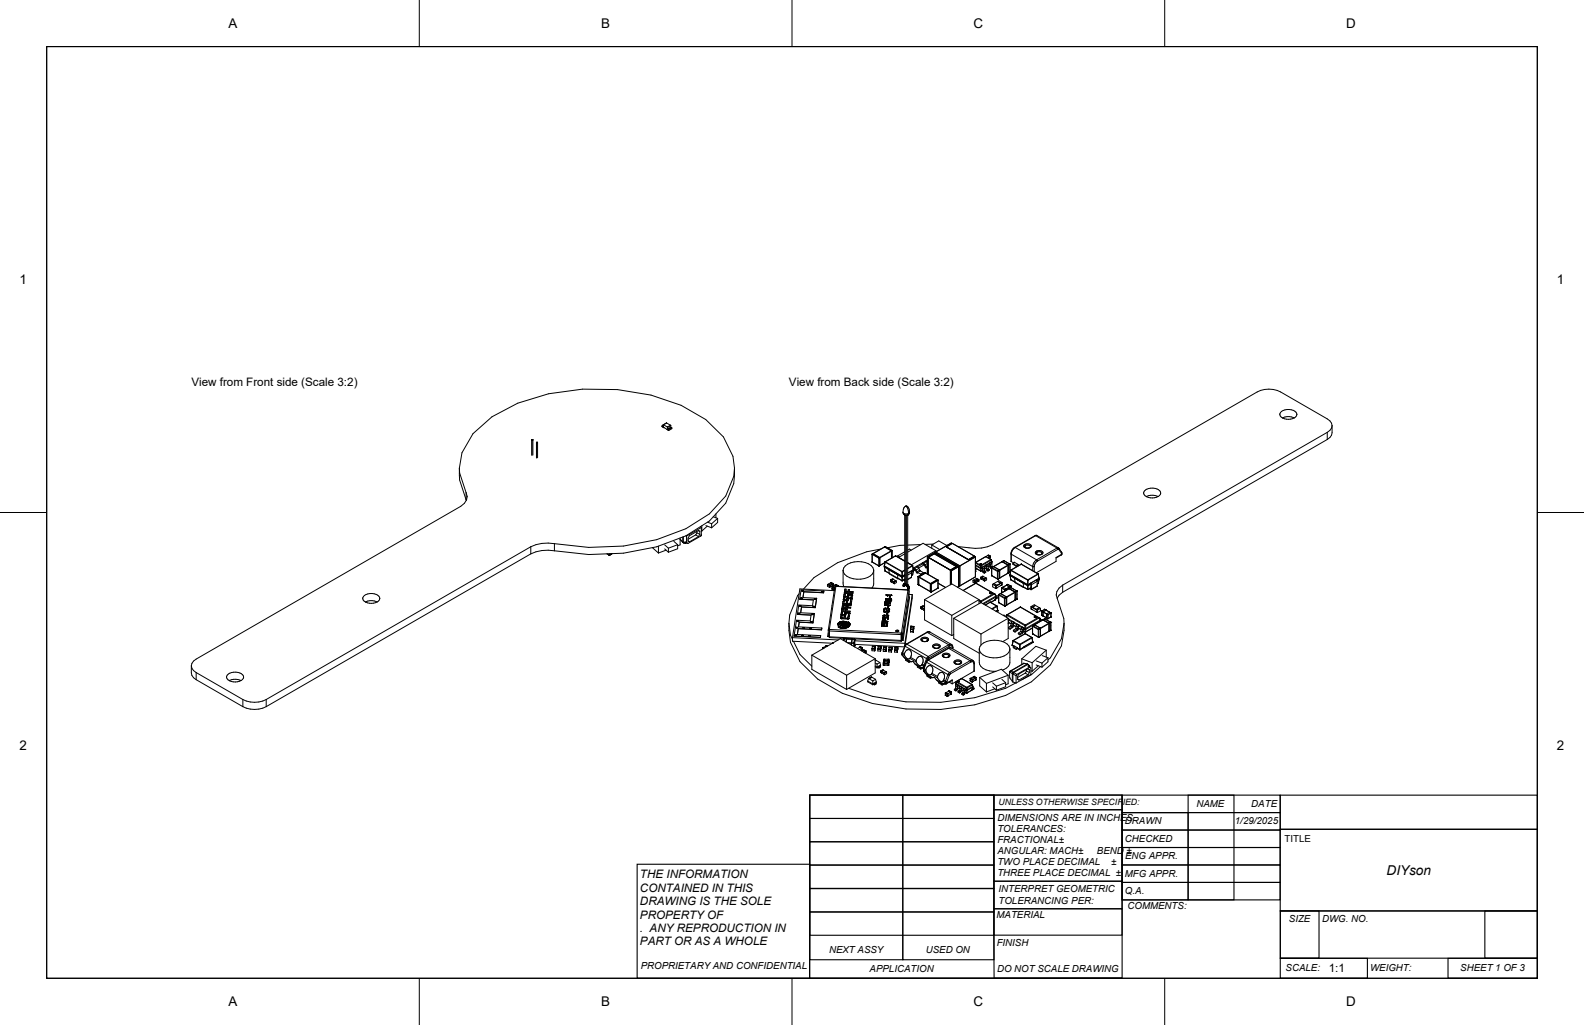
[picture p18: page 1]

UNLESS OTHERWISE SPECIFIED: | | NAME | DATE
DIMENSIONS ARE IN INCHES TOLERANCES: FRACTIONAL± ANGULAR: MACH± BEND ± TWO PLACE DECIMAL ± THREE PLACE DECIMAL ± | DRAWN | | 1/29/2025

CHECKED | | | TITLE DIYson
ENG APPR.

THE INFORMATION CONTAINED IN THIS DRAWING IS THE SOLE PROPERTY OF . ANY REPRODUCTION IN PART OR AS A WHOLE PROPRIETARY AND CONFIDENTIAL | | | MFG APPR.

INTERPRET GEOMETRIC TOLERANCING PER: | Q.A.

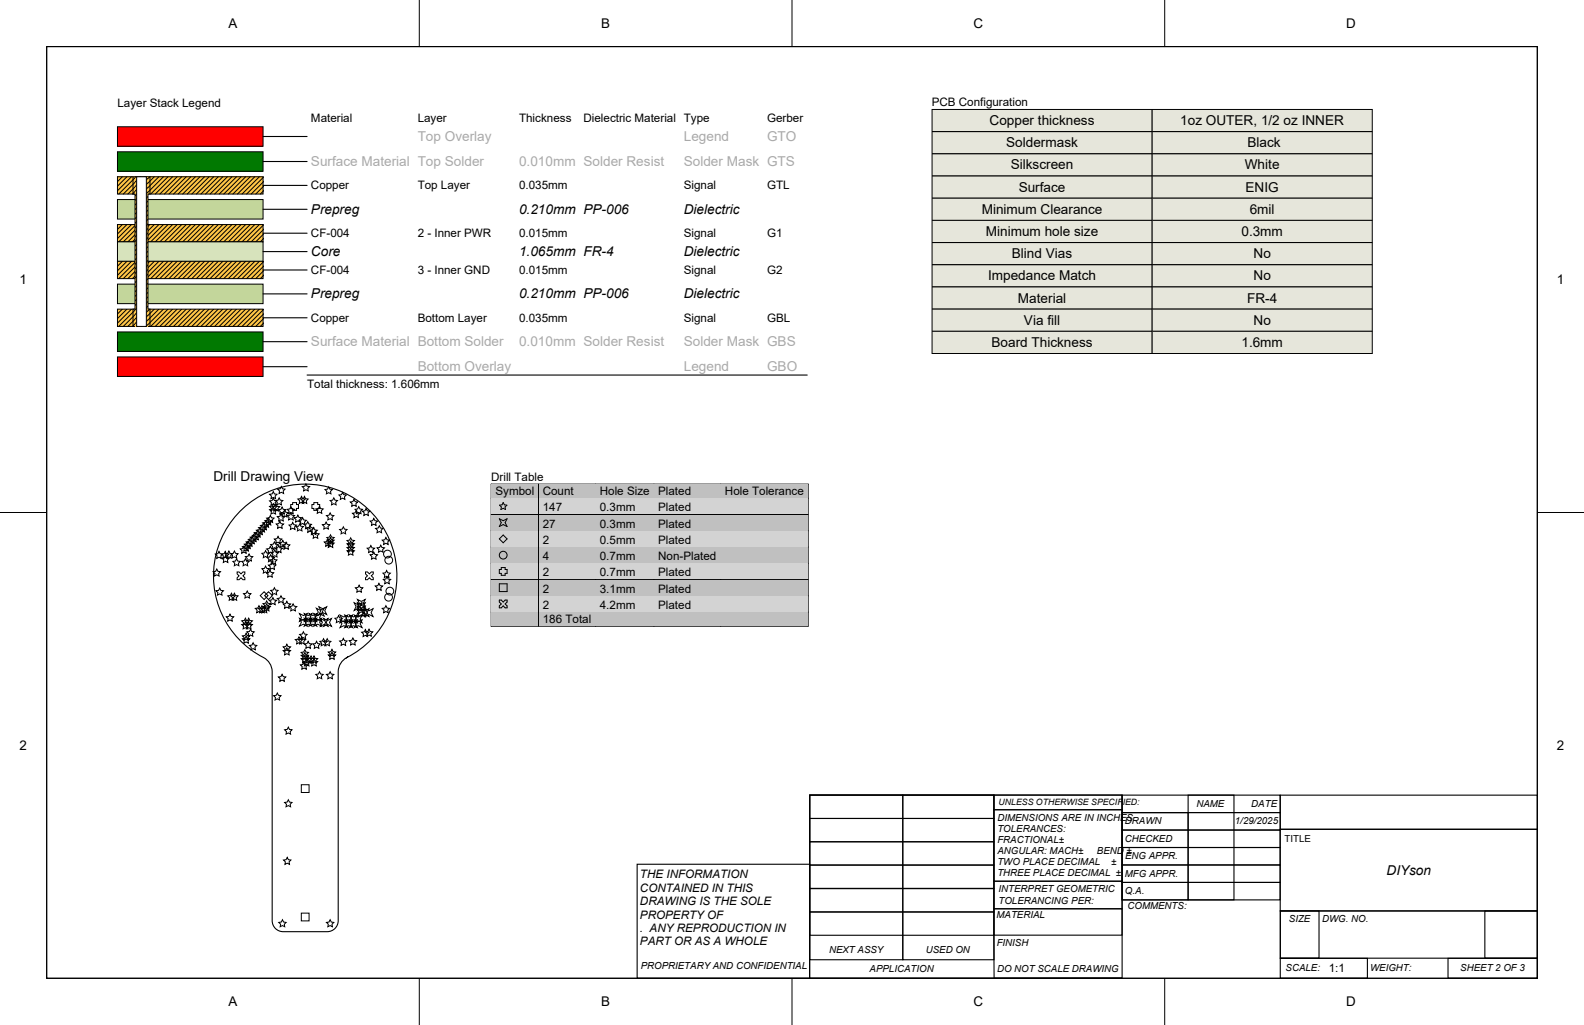
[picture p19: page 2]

Copper thickness | 1oz OUTER, 1/2 oz INNER
Soldermask | Black
Silkscreen | White
Surface | ENIG
Minimum Clearance | 6mil
Minimum hole size | 0.3mm
Blind Vias | No
Impedance Match | No
Material | FR-4
Via fill | No
Board Thickness | 1.6mm

Symbol | Count | Hole Size | Plated | Hole Tolerance

147 | 0.3mm | Plated
27 | 0.3mm | Plated
2 | 0.5mm | Plated
4 | 0.7mm | Non-Plated
2 | 0.7mm | Plated
2 | 3.1mm | Plated
2 | 4.2mm | Plated
186 Total

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

CHECKED | | | TITLE DIYson
ENG APPR.

THE INFORMATION CONTAINED IN THIS DRAWING IS THE SOLE PROPERTY OF . ANY REPRODUCTION IN | | | MFG APPR.

INTERPRET GEOMETRIC TOLERANCING PER: | Q.A.

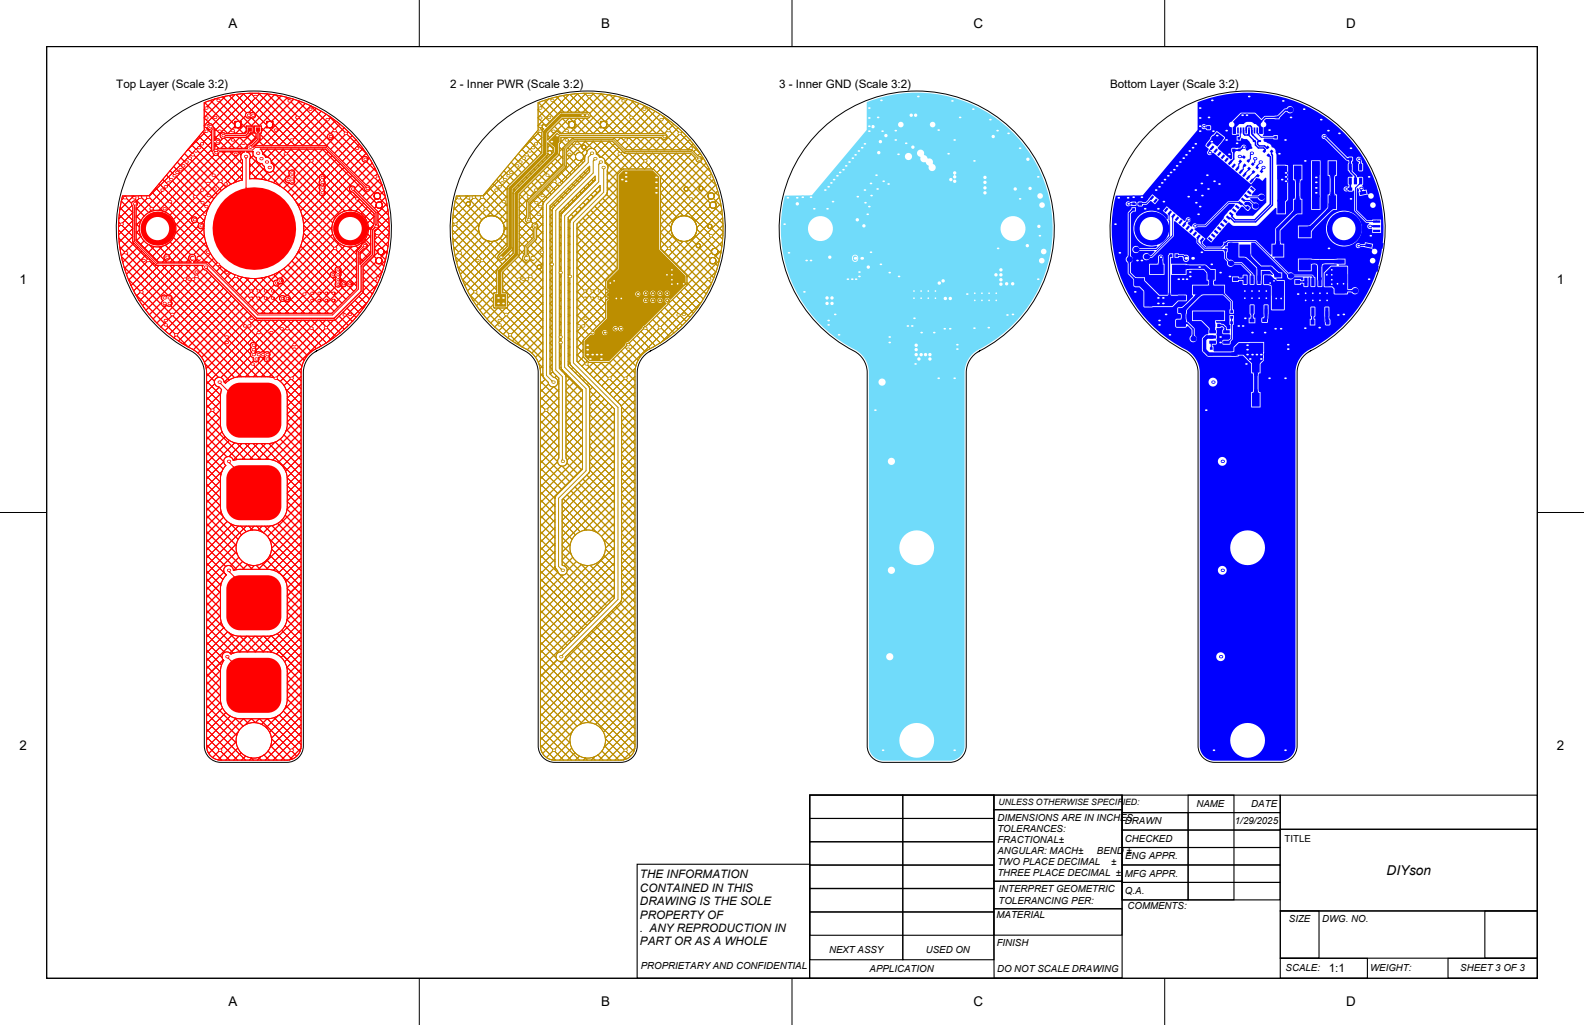
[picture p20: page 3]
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

CHECKED | | | TITLE DIYson
ENG APPR.

THE INFORMATION CONTAINED IN THIS DRAWING IS THE SOLE PROPERTY OF . ANY REPRODUCTION IN | | | MFG APPR.

INTERPRET GEOMETRIC TOLERANCING PER: | Q.A.

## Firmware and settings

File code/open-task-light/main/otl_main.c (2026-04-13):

// otl_main.c - Open Task Light firmware (ESP-IDF, ESP32-S3)
// PWM dimming, capacitive-touch UI, WS2812 RGB status LED, ADC sensors,
// optional LD2410B presence sensor, optional circadian color temperature.

#include <stdio.h>
#include <stdlib.h>
#include <math.h>
#include <string.h>
#include <time.h>
#include "sdkconfig.h"
#include "esp_idf_version.h"
#include "freertos/FreeRTOS.h"
#include "freertos/task.h"
#include "freertos/semphr.h"
#include "esp_check.h"
#include "esp_log.h"

static bool otl_runtime_status_logging_enabled(void);
static bool otl_runtime_sensor_debug_logging_enabled(void);
static bool otl_runtime_touch_event_logging_enabled(void);
static bool otl_runtime_touch_calibration_logging_enabled(void);
static bool otl_runtime_touch_raw_logging_enabled(void);
static bool otl_runtime_pwm_duty_logging_enabled(void);
static bool otl_runtime_radar_status_logging_enabled(void);
static bool otl_runtime_occupancy_auto_off_enabled(void);

#if CONFIG_OTL_SERIAL_OUTPUT
#define OTL_LOGI(tag, fmt, ...) ESP_LOGI(tag, fmt, ##__VA_ARGS__)
#define OTL_LOGW(tag, fmt, ...) ESP_LOGW(tag, fmt, ##__VA_ARGS__)
#define OTL_LOGE(tag, fmt, ...) ESP_LOGE(tag, fmt, ##__VA_ARGS__)
#define OTL_LOGD(tag, fmt, ...) ESP_LOGD(tag, fmt, ##__VA_ARGS__)
#define OTL_LOGI_PERIODIC(tag, fmt, ...) do { \
    char _otl_ts[32]; \
    ESP_LOGI(tag, "[%s] " fmt, otl_log_localtime(_otl_ts, sizeof(_otl_ts)), ##__VA_ARGS__); \
} while (0)
#else
#define OTL_LOGI(tag, fmt, ...) do { (void)(tag); (void)(fmt); } while (0)
#define OTL_LOGW(tag, fmt, ...) do { (void)(tag); (void)(fmt); } while (0)
#define OTL_LOGE(tag, fmt, ...) do { (void)(tag); (void)(fmt); } while (0)
#define OTL_LOGD(tag, fmt, ...) do { (void)(tag); (void)(fmt); } while (0)
#define OTL_LOGI_PERIODIC(tag, fmt, ...) do { (void)(tag); (void)(fmt); } while (0)
#endif

#if CONFIG_OTL_SERIAL_OUTPUT
#define OTL_LOG_STATUSI(fmt, ...) do { \
    if (otl_runtime_status_logging_enabled()) { \
        OTL_LOGI_PERIODIC("sensor", fmt, ##__VA_ARGS__); \
    } \
} while (0)
#else
#define OTL_LOG_STATUSI(fmt, ...) do { (void)(fmt); } while (0)
#endif

#if CONFIG_OTL_SERIAL_OUTPUT
#define OTL_LOG_TOUCHI(fmt, ...) do { \
    if (otl_runtime_touch_event_logging_enabled()) { \
        OTL_LOGI("touch", fmt, ##__VA_ARGS__); \
    } \
} while (0)
#else
#define OTL_LOG_TOUCHI(fmt, ...) do { (void)(fmt); } while (0)
#endif

#if CONFIG_OTL_SERIAL_OUTPUT
#define OTL_LOG_TOUCH_CALI(fmt, ...) do { \
    if (otl_runtime_touch_calibration_logging_enabled()) { \
        OTL_LOGI_PERIODIC("touch", fmt, ##__VA_ARGS__); \
    } \
} while (0)
#else
#define OTL_LOG_TOUCH_CALI(fmt, ...) do { (void)(fmt); } while (0)
#endif

#if CONFIG_OTL_SERIAL_OUTPUT
#define OTL_LOG_RADARI(fmt, ...) do { \
    if (otl_runtime_radar_status_logging_enabled()) { \
        OTL_LOGI_PERIODIC("radar", fmt, ##__VA_ARGS__); \
    } \
} while (0)
#else
#define OTL_LOG_RADARI(fmt, ...) do { (void)(fmt); } while (0)
#endif

static const char *otl_log_localtime(char *buf, size_t buf_len) __attribute__((unused));
static const char *otl_log_localtime(char *buf, size_t buf_len)
{
    if (buf == NULL || buf_len == 0) {
        return "time=unset";
    }

    time_t now = 0;
    struct tm timeinfo = {0};
    time(&now);
    localtime_r(&now, &timeinfo);

    // Year since 1900. Anything pre-2020 is almost certainly "not synced".
    if (timeinfo.tm_year < (2020 - 1900)) {
        return "time=unset";
    }

    if (strftime(buf, buf_len, "%Y-%m-%d %H:%M:%S", &timeinfo) == 0) {
        return "time=unset";
    }

    return buf;
}
#include "esp_timer.h"
#include "esp_wifi.h"
#include "driver/ledc.h"
#include "driver/touch_pad.h"
#include "esp_adc/adc_oneshot.h"
#include "driver/gpio.h"
#include "driver/temperature_sensor.h"
#if CONFIG_OTL_PRESENCE_SENSOR
#include "driver/uart.h"
#endif
#include "led_strip.h" 
#include "esp_adc/adc_cali.h"
#include "esp_adc/adc_cali_scheme.h"
#include "freertos/queue.h"
#include "esp_intr_alloc.h"
#include "nvs.h"
#include "nvs_flash.h"
#include "otl_circadian.h"
#include "otl_homekit.h"
#include "otl_mqtt.h"
#include "otl_net.h"
#include "otl_runtime.h"

#if ESP_IDF_VERSION >= ESP_IDF_VERSION_VAL(5, 2, 0)
#define OTL_ADC_ATTEN ADC_ATTEN_DB_12
#else
#define OTL_ADC_ATTEN ADC_ATTEN_DB_11
#endif

static adc_cali_handle_t adc2_cali_handle = NULL;

#if CONFIG_OTL_PRESENCE_SENSOR
// --- Radar UART ---
#define RADAR_UART_NUM UART_NUM_1
static const int RADAR_UART_BAUD = 256000;  // LD2410 default

typedef struct {
    bool    valid;
    uint8_t targetType;    // bit0=moving, bit1=stationary
    uint16_t movingDist;   // cm
    uint8_t movingEnergy;  // 0-100
    uint16_t staticDist;   // cm
    uint8_t staticEnergy;  // 0-100
} radar_sample_t;

static radar_sample_t radar_last_sample = {0};
static uint32_t radar_last_sample_ms = 0;

// Simple UART RX buffer for LD2410 frames
static uint8_t radar_rx_buf[128];
static size_t  radar_rx_len = 0;
static const uint8_t radar_cmd_enter_config[] = {
    0xFD, 0xFC, 0xFB, 0xFA, 0x04, 0x00, 0xFF, 0x00, 0x01, 0x00, 0x04, 0x03, 0x02, 0x01
};
static const uint8_t radar_cmd_disable_bluetooth[] = {
    0xFD, 0xFC, 0xFB, 0xFA, 0x04, 0x00, 0xA4, 0x00, 0x00, 0x00, 0x04, 0x03, 0x02, 0x01
};
static const uint8_t radar_cmd_restart[] = {
    0xFD, 0xFC, 0xFB, 0xFA, 0x02, 0x00, 0xA3, 0x00, 0x04, 0x03, 0x02, 0x01
};
static const uint8_t radar_cmd_end_config[] = {
    0xFD, 0xFC, 0xFB, 0xFA, 0x02, 0x00, 0xFE, 0x00, 0x04, 0x03, 0x02, 0x01
};
    
#endif

#ifndef MIN
#define MIN(a,b) (((a)<(b))?(a):(b))
#endif
#ifndef MAX
#define MAX(a,b) (((a)>(b))?(a):(b))
#endif

// --- Application-wide timing constants ---
#define TOUCH_MEAS_WAIT_MS        250   // Max wait for touch measurement to complete
#define TOUCH_SETTLE_MS           250   // Delay for filter/FSM to settle before calibration
#define SENSOR_READ_INTERVAL_MS   10000 // Interval between sensor log lines
#define THERMAL_POLL_INTERVAL_MS  1000  // Interval between thermal checks
#define RECALIB_INTERVAL_MS       60000 // Interval between touch recalibration attempts
#define RADAR_MAX_ENERGY          100   // Maximum energy value from LD2410 radar
#define TOUCH_STARTUP_MAX_RETRIES 4     // Retry startup calibration if pads are still settling
#define TOUCH_STARTUP_RETRY_MS    150   // Delay between startup calibration retries
#define TOUCH_RECOVERY_DELAY_MS   2000  // Early post-boot recalibration pass
#define TOUCH_VERIFY_DELAY_MS     100   // Delay between touch verification samples
#define TOUCH_VERIFY_SAMPLES      3     // Consecutive samples required for a stuck-touch recovery
#define TOUCH_BAD_PRESSED_PADS    3     // Number of simultaneously "pressed" pads treated as a bad calibration

static inline uint32_t clamp_u32(uint32_t v, uint32_t lo, uint32_t hi)
{
    if (v < lo) return lo;
    if (v > hi) return hi;
    return v;
}

// ---------------------------- Pin definitions ----------------------------
// Touch pads
#define TOUCH_LED_SWITCH   TOUCH_PAD_NUM7       // GPIO7
#define TOUCH_SWITCH_UP    TOUCH_PAD_NUM8       // GPIO8
#define TOUCH_SWITCH_DN    TOUCH_PAD_NUM9       // GPIO9
#define TOUCH_TEMP_UP      TOUCH_PAD_NUM10      // GPIO10
#define TOUCH_TEMP_DN      TOUCH_PAD_NUM11      // GPIO11

#if CONFIG_OTL_PRESENCE_SENSOR
#define RADAR_OUT_GPIO     15   // LD2410B digital OUT (occupancy) - candidate 1
#define RADAR_OUT_GPIO_ALT 14   // LD2410B digital OUT (occupancy) - candidate 2
// Optional: UART pins if you later want full LD2410B frame parsing
// Module pin 39 -> GPIO43, module pin 40 -> GPIO44 on ESP32-S3-MINI-1-N4R2
#define RADAR_TX_GPIO      43   // ESP32 TX (GPIO43) -> radar RX (module pin 39)
#define RADAR_RX_GPIO      44   // ESP32 RX (GPIO44) <- radar TX (module pin 40)
#endif

#define DIM_OUT_COOL_GPIO  36   // PWM output for cool white
#define DIM_OUT_WARM_GPIO  35   // PWM output for warm white
#define WS2812_GPIO        40   // RMT / LED-Strip output pin

#define ALS_GPIO           5    // ALS‑PT19 analog input (ADC)
#define NTC_GPIO           16   // NTC thermistor divider analog input (ADC)

// ---------------------------- LEDC PWM ----------------------------
#define OTL_LEDC_DUTY_RES LEDC_TIMER_12_BIT
#define OTL_LEDC_FREQ_HZ  19531
#define OTL_PWM_MAX_DUTY  ((1U << OTL_LEDC_DUTY_RES) - 1U)

// Minimum PWM "on" pulse width (per channel). Any non-zero duty below this
// threshold is clamped up to avoid sub-min pulses.
//
// 0.3us @ 19.531kHz/12-bit => 24 duty counts.
#define OTL_PWM_MIN_ON_TIME_NS 300ULL // 0.3us
#define OTL_PWM_MIN_ON_DUTY_RAW \
    ((uint32_t)(((OTL_PWM_MIN_ON_TIME_NS * (uint64_t)OTL_LEDC_FREQ_HZ * (uint64_t)OTL_PWM_MAX_DUTY) + 1000000000ULL - 1ULL) / 1000000000ULL))
#define OTL_PWM_MIN_ON_DUTY \
    ((OTL_PWM_MIN_ON_DUTY_RAW < 1U) ? 1U : ((OTL_PWM_MIN_ON_DUTY_RAW > OTL_PWM_MAX_DUTY) ? OTL_PWM_MAX_DUTY : OTL_PWM_MIN_ON_DUTY_RAW))

static const ledc_timer_config_t ledc_timer_cfg = {
    .speed_mode       = LEDC_LOW_SPEED_MODE,
    .duty_resolution  = OTL_LEDC_DUTY_RES,
    .timer_num        = LEDC_TIMER_0,
    // Pick a frequency that keeps the LEDC divider close to 1 for the chosen
    // duty resolution (80MHz / 2^N => ~19.5kHz @ 12-bit, ~9.8kHz @ 13-bit,
    // ~4.9kHz @ 14-bit).
    .freq_hz          = OTL_LEDC_FREQ_HZ,
    .clk_cfg          = LEDC_AUTO_CLK
};

static ledc_channel_config_t ledc_ch_cool = {
    .gpio_num   = DIM_OUT_COOL_GPIO,
    .speed_mode = LEDC_LOW_SPEED_MODE,
    .channel    = LEDC_CHANNEL_0,
    .timer_sel  = LEDC_TIMER_0,
    .duty       = 0,
    .hpoint     = 0
};
static ledc_channel_config_t ledc_ch_warm = {
    .gpio_num   = DIM_OUT_WARM_GPIO,
    .speed_mode = LEDC_LOW_SPEED_MODE,
    .channel    = LEDC_CHANNEL_1,
    .timer_sel  = LEDC_TIMER_0,
    .duty       = 0,
    .hpoint     = 0
};
static const uint32_t PWM_MAX_DUTY = OTL_PWM_MAX_DUTY;
static const uint32_t PWM_MIN_ON_DUTY = OTL_PWM_MIN_ON_DUTY;

// ---------------------------- WS2812 (RMT LED-Strip) ----------------------------
 #define WS2812_NUM_PIXELS  1
 static led_strip_handle_t strip;
 static bool neopixel_enabled = false;

// ---------------------------- PWM fade smoothing -------------------------------
// Fade between duty targets in hardware so we don't "skip" duty steps.
// Used by the hold stepper (0->max in ~1.2s at 12-bit/95% cap).
#define PWM_HOLD_STEP_UPDATE_US       600
#define PWM_FADE_STEP                 1
// Try to keep fade duration roughly constant for small deltas so you don't get
// "step + settle" behavior at low brightness.
#define PWM_FADE_TARGET_TIME_MS       10
// Faster turn-off fade: use a larger duty step so we aren't limited to
// "1 duty count per PWM period" at high brightness.
#define PWM_FADE_OFF_STEP             2
#define PWM_FADE_OFF_TIME_MS          100
#define PWM_FADE_MAX_CYCLES_PER_STEP  1000

static inline uint32_t pwm_clamp_min_on_duty(uint32_t duty)
{
    if (duty == 0) {
        return 0;
    }
    if (duty < PWM_MIN_ON_DUTY) {
        return PWM_MIN_ON_DUTY;
    }
    return duty;
}

#if !CONFIG_OTL_NONOVERLAP_PWM
typedef struct {
    ledc_mode_t    speed_mode;
    ledc_channel_t channel;
} pwm_off_timer_arg_t;

static esp_timer_handle_t pwm_off_timer_cool = NULL;
static esp_timer_handle_t pwm_off_timer_warm = NULL;

static pwm_off_timer_arg_t pwm_off_args_cool = {
    .speed_mode = LEDC_LOW_SPEED_MODE,
    .channel = LEDC_CHANNEL_0,
};
static pwm_off_timer_arg_t pwm_off_args_warm = {
    .speed_mode = LEDC_LOW_SPEED_MODE,
    .channel = LEDC_CHANNEL_1,
};

static void pwm_off_timer_cb(void *arg)
{
    const pwm_off_timer_arg_t *a = (const pwm_off_timer_arg_t *)arg;
    (void)ledc_set_duty_and_update(a->speed_mode, a->channel, 0, 0);
}

static inline esp_timer_handle_t pwm_off_timer_for_channel(ledc_channel_t channel)
{
    if (channel == ledc_ch_cool.channel) {
        return pwm_off_timer_cool;
    }
    if (channel == ledc_ch_warm.channel) {
        return pwm_off_timer_warm;
    }
    return NULL;
}
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
void app_main(void)
{
#if !CONFIG_OTL_SERIAL_OUTPUT
    esp_log_level_set("*", ESP_LOG_NONE);
#endif

    // 1. LEDC PWM
    ESP_ERROR_CHECK(ledc_timer_config(&ledc_timer_cfg));
    ESP_ERROR_CHECK(ledc_channel_config(&ledc_ch_cool));
    ESP_ERROR_CHECK(ledc_channel_config(&ledc_ch_warm));
    ESP_ERROR_CHECK(ledc_fade_func_install(0));

    const esp_timer_create_args_t pwm_hold_step_timer_args = {
        .callback = &pwm_hold_stepper_timer_cb,
        .arg = NULL,
        .dispatch_method = ESP_TIMER_TASK,
        .name = "pwm_hold_stepper",
        .skip_unhandled_events = true,
    };
    ESP_ERROR_CHECK(esp_timer_create(&pwm_hold_step_timer_args, &pwm_hold_step_timer));
#if !CONFIG_OTL_NONOVERLAP_PWM
    const esp_timer_create_args_t pwm_off_timer_cool_args = {
        .callback = &pwm_off_timer_cb,
        .arg = &pwm_off_args_cool,
        .dispatch_method = ESP_TIMER_TASK,
        .name = "pwm_off_cool",
        .skip_unhandled_events = true,
    };
    ESP_ERROR_CHECK(esp_timer_create(&pwm_off_timer_cool_args, &pwm_off_timer_cool));

    const esp_timer_create_args_t pwm_off_timer_warm_args = {
        .callback = &pwm_off_timer_cb,
        .arg = &pwm_off_args_warm,
        .dispatch_method = ESP_TIMER_TASK,
        .name = "pwm_off_warm",
        .skip_unhandled_events = true,
    };
    ESP_ERROR_CHECK(esp_timer_create(&pwm_off_timer_warm_args, &pwm_off_timer_warm));
#endif
#if CONFIG_OTL_NONOVERLAP_PWM
    pwm_nonoverlap_mutex = xSemaphoreCreateMutex();
    if (pwm_nonoverlap_mutex == NULL) {
        abort();
    }
    const esp_timer_create_args_t pwm_timer_args = {
        .callback = &pwm_nonoverlap_timer_cb,
        .arg = NULL,
        .dispatch_method = ESP_TIMER_TASK,
        .name = "pwm_nonoverlap",
        .skip_unhandled_events = true,
    };
    ESP_ERROR_CHECK(esp_timer_create(&pwm_timer_args, &pwm_nonoverlap_timer));
    ESP_ERROR_CHECK(esp_timer_start_periodic(pwm_nonoverlap_timer, PWM_SOFT_FADE_UPDATE_US));
#endif

#if CONFIG_OTL_SERIAL_OUTPUT
    const esp_timer_create_args_t pwm_log_timer_args = {
        .callback = &pwm_log_timer_cb,
        .arg = NULL,
        .dispatch_method = ESP_TIMER_TASK,
        .name = "pwm_log",
        .skip_unhandled_events = true,
    };
    ESP_ERROR_CHECK(esp_timer_create(&pwm_log_timer_args, &pwm_log_timer));
    ESP_ERROR_CHECK(esp_timer_start_periodic(pwm_log_timer,
                                             (uint64_t)OTL_RUNTIME_PWM_LOG_INTERVAL_MS * 1000ULL));
#endif

    otl_state_mutex = xSemaphoreCreateMutex();
    if (otl_state_mutex == NULL) {
        abort();
    }

    esp_err_t runtime_settings_err = otl_runtime_settings_init();
    if (runtime_settings_err != ESP_OK) {
        OTL_LOGE("runtime", "Settings init failed: %s", esp_err_to_name(runtime_settings_err));
    }

    // 2. WS2812 via RMT LED-Strip driver
    led_strip_config_t strip_config = {
        .strip_gpio_num   = WS2812_GPIO,
        .max_leds         = WS2812_NUM_PIXELS,
        .led_model        = LED_MODEL_WS2812,
        .flags.invert_out = false,
    };
    led_strip_rmt_config_t rmt_cfg = {
        .clk_src   = RMT_CLK_SRC_DEFAULT,
        .resolution_hz = 10 * 1000 * 1000, // 10 MHz
        .mem_block_symbols = 64,
        .flags.with_dma = false,
    };
    ESP_ERROR_CHECK(led_strip_new_rmt_device(&strip_config, &rmt_cfg, &strip));
    led_strip_clear(strip);

    // 3. Radar OUT pin (LD2410B occupancy) + UART for moving/stationary
#if CONFIG_OTL_PRESENCE_SENSOR
    gpio_config_t radar_cfg = {
        .pin_bit_mask = (1ULL << RADAR_OUT_GPIO) | (1ULL << RADAR_OUT_GPIO_ALT),
        .mode = GPIO_MODE_INPUT,
        .pull_up_en = GPIO_PULLUP_DISABLE,
        .pull_down_en = GPIO_PULLDOWN_ENABLE,
        .intr_type = GPIO_INTR_DISABLE
    };
    ESP_ERROR_CHECK(gpio_config(&radar_cfg));

    // Radar UART (LD2410B) configuration
    uart_config_t uart_cfg = {
        .baud_rate  = RADAR_UART_BAUD,
        .data_bits  = UART_DATA_8_BITS,
        .parity     = UART_PARITY_DISABLE,
        .stop_bits  = UART_STOP_BITS_1,
        .flow_ctrl  = UART_HW_FLOWCTRL_DISABLE,
        .source_clk = UART_SCLK_DEFAULT,
    };
    ESP_ERROR_CHECK(uart_driver_install(RADAR_UART_NUM, 1024, 0, 0, NULL, 0));
    ESP_ERROR_CHECK(uart_param_config(RADAR_UART_NUM, &uart_cfg));
    ESP_ERROR_CHECK(uart_set_pin(RADAR_UART_NUM,
                                 RADAR_TX_GPIO,  // TX -> radar RX
                                 RADAR_RX_GPIO,  // RX <- radar TX
                                 UART_PIN_NO_CHANGE,
                                 UART_PIN_NO_CHANGE));
#if CONFIG_OTL_RADAR_DISABLE_BLUETOOTH_AT_BOOT
    esp_err_t radar_bt_err = radar_disable_bluetooth_if_needed();
    if (radar_bt_err != ESP_OK) {
        OTL_LOGW("radar", "LD2410B Bluetooth disable failed: %s", esp_err_to_name(radar_bt_err));
    }
#endif
#endif

    // 4. Touch pads - dynamic baseline / threshold (value rises on touch)
    ESP_ERROR_CHECK(touch_pad_init());

    for (int i = 0; i < PAD_COUNT; ++i) {
        ESP_ERROR_CHECK(touch_pad_config(touch_pads[i]));
        // Standard configuration; on this board raw value rises when touched
        ESP_ERROR_CHECK(touch_pad_set_cnt_mode(touch_pads[i],
                                               TOUCH_PAD_SLOPE_7,
                                               TOUCH_PAD_TIE_OPT_LOW));
    }

    // General touch sensing parameters
    ESP_ERROR_CHECK(touch_pad_set_charge_discharge_times(5));
    ESP_ERROR_CHECK(touch_pad_set_voltage(TOUCH_HVOLT_2V7, TOUCH_LVOLT_0V5, TOUCH_HVOLT_ATTEN_0V));
    // Shorter measurement interval for faster response (~30–40 ms between updates)
    ESP_ERROR_CHECK(touch_pad_set_measurement_interval(1000));

    // Filter configuration
    touch_filter_config_t filter_config = {
        .mode = TOUCH_PAD_FILTER_IIR_16,
        .debounce_cnt = 2,
        .noise_thr = 3,
        .jitter_step = 6,
        .smh_lvl = TOUCH_PAD_SMOOTH_IIR_4,
    };
    ESP_ERROR_CHECK(touch_pad_filter_set_config(&filter_config));
    ESP_ERROR_CHECK(touch_pad_filter_enable());
    
    // Start the touch FSM
    ESP_ERROR_CHECK(touch_pad_set_fsm_mode(TOUCH_FSM_MODE_TIMER));
    ESP_ERROR_CHECK(touch_pad_fsm_start());

    // Wait for measuring to complete (this can take longer after cold boot / when
    // power/ground conditions change, so don't assume it is instant).
    TickType_t t0 = xTaskGetTickCount();
    while (!touch_pad_meas_is_done() &&
           (xTaskGetTickCount() - t0) < pdMS_TO_TICKS(TOUCH_MEAS_WAIT_MS)) {
        vTaskDelay(pdMS_TO_TICKS(1));
    }

    // Let the filter/FSM settle before sampling baselines.
    vTaskDelay(pdMS_TO_TICKS(TOUCH_SETTLE_MS));

    // Calibrate touch pads using Arduino-style baseline/thresholds.
    // Cold power-on can leave the touch front-end drifting for a short time,
    // so validate the first calibration and retry if needed.
    touch_calibrate_startup();

    // Using polling-based touch handling in touch_task() instead of ISR

    // 5. ADC (ALS + NTC)
    adc_init();

    // 5b. ESP32 internal temperature sensor
    chip_temp_init();
    thermal_brightness_cap_percent = (float)MAX_BRIGHTNESS_PERCENT;

#if CONFIG_OTL_WIFI_ENABLE
    esp_err_t wifi_err = otl_net_start_wifi();
    if (wifi_err != ESP_OK) {
        OTL_LOGE("wifi", "Start failed: %s", esp_err_to_name(wifi_err));
    }
#endif

#if CONFIG_OTL_CIRCADIAN_ENABLE
    esp_err_t circadian_err = otl_circadian_start(otl_circadian_apply_cb,
                                                  NULL,
                                                  otl_circadian_schedule_getter,
                                                  NULL);
    if (circadian_err != ESP_OK) {
        OTL_LOGE("circadian", "Start failed: %s", esp_err_to_name(circadian_err));
    }
#endif

#if CONFIG_OTL_HA_MQTT_ENABLE
    esp_err_t mqtt_err = otl_mqtt_start();
    if (mqtt_err != ESP_OK) {
        OTL_LOGE("mqtt", "Start failed: %s", esp_err_to_name(mqtt_err));
    }
#endif

#if CONFIG_OTL_HOMEKIT_ENABLE
    esp_err_t homekit_err = otl_homekit_start();
    if (homekit_err != ESP_OK) {
        OTL_LOGE("homekit", "Start failed: %s", esp_err_to_name(homekit_err));
    }
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

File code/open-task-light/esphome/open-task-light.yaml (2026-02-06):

substitutions:
  name: open-task-light
  friendly_name: Open Task Light
  fallback_ap_password: "open-task-light"
  # If mDNS doesn't work in your network, set this to the device IP (e.g. "192.168.1.50").
  use_address: "${name}.local"

  # `esp32_touch` binary_sensor thresholds are kept high because touch actions
  # are handled by a custom polling state machine below.
  touch_threshold_power: "50000"
  touch_threshold_brightness_up: "50000"
  touch_threshold_brightness_dn: "50000"
  touch_threshold_temp_up: "50000"
  touch_threshold_temp_dn: "50000"

  # Touch engine tuning.
  touch_engine_scan_interval: 10ms
  touch_engine_debug_interval_ms: "250"
  touch_engine_on_debounce_ticks: "2"
  touch_engine_off_debounce_ticks: "2"
  touch_engine_winner_margin: "30"
  touch_engine_hold_power_ms: "3000"
  # If power remains active too long after a tap, allow an early release when
  # the signal has decayed close to the on-threshold.
  touch_engine_power_forced_release_ms: "700"
  touch_engine_power_release_margin: "900"
  touch_engine_tap_max_ms: "700"
  touch_engine_double_tap_window_ms: "450"
  touch_engine_baseline_shift: "5"      # baseline alpha = 1/32
  touch_engine_noise_shift: "4"         # noise alpha = 1/16
  touch_engine_min_signal_power: "160"
  touch_engine_min_signal_brightness_up: "90"
  touch_engine_min_signal_brightness_dn: "90"
  touch_engine_min_signal_temp_up: "90"
  touch_engine_min_signal_temp_dn: "110"
  touch_engine_min_release_signal: "28"
  touch_engine_noise_mult_power: "8"
  touch_engine_noise_mult_buttons: "6"
  touch_engine_max_signal_power: "2400"
  touch_engine_max_signal_buttons: "900"

  # Calibration/reseed timing.
  touch_cal_settle_delay: 1200ms

  # Touch hold timing (tuning).
  # - Smaller repeat delay = faster changes while holding a pad.
  # - Keep this >= ~10ms to avoid excessive state spam / CPU load.
  touch_hold_initial_delay_ms: "60"
  touch_hold_repeat_delay_ms: "16"
  touch_hold_brightness_step: "0.0075f"    # 0.75% per repeat
  touch_hold_ct_step_mired: "4.0f"         # mireds per repeat
  touch_tap_brightness_step: "0.015f"      # 1.5% per tap
  touch_tap_ct_step_mired: "4.0f"          # mireds per tap

  # Pin map (mirrors main/otl_main.c)
  pin_pwm_warm: GPIO35
  pin_pwm_cool: GPIO36
  pin_ws2812: GPIO40
  pin_touch_power: GPIO7
  pin_touch_brightness_up: GPIO8
  pin_touch_brightness_dn: GPIO9
  pin_touch_temp_up: GPIO10
  pin_touch_temp_dn: GPIO11
  pin_radar_tx: GPIO43
  pin_radar_rx: GPIO44
  pin_radar_out: GPIO15

esphome:
  name: ${name}
  friendly_name: ${friendly_name}
  on_boot:
    # Run after components have initialized so `esp32_touch` has valid readings.
    priority: -10
    then:
      - script.execute: calibrate_touch_thresholds 

esp32:
  board: esp32-s3-devkitc-1
  framework:
    type: esp-idf
    # ESP-IDF v5+ deprecates the legacy touch API that ESPHome currently uses.
    # This suppresses the build warning without changing behavior.
    sdkconfig_options:
      CONFIG_TOUCH_SUPPRESS_DEPRECATE_WARN: "y"

wifi:
  ssid: !secret wifi_ssid
  password: !secret wifi_password
  # Reduce command latency (ESP32 Wi-Fi modem sleep can add seconds of lag).
  power_save_mode: none
  # Optional: set a static IP (recommended if you set `use_address` to an IP).
  # manual_ip:
  #   static_ip: 192.168.1.50
  #   gateway: 192.168.1.1
  #   subnet: 255.255.255.0
  #   dns1: 192.168.1.1
  # Address used by ESPHome for API/OTA uploads. Use a static IP here if mDNS
  # resolution fails (the default "${name}.local" requires mDNS).
  use_address: "${use_address}"
  ap:
    ssid: "${friendly_name} Fallback"
    # If you prefer to store this in Home Assistant secrets.yaml, replace with:
    #   password: !secret wifi_fallback_password
    password: "${fallback_ap_password}"

captive_portal:

api:

ota:
  - platform: esphome

# Local device web UI at `http://open-task-light.local` (or the configured IP).
web_server:
  port: 80

# Set `baud_rate: 0` to disable serial logs (mirrors CONFIG_OTL_SERIAL_OUTPUT off).
logger:
  baud_rate: 115200
  # Set to DEBUG temporarily when tuning touch thresholds.
  level: INFO
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

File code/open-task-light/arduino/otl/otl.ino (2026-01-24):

#include <Arduino.h>
#include <Adafruit_NeoPixel.h>
#include <driver/ledc.h>

// Pin Definitions
const uint8_t ledSwitch = T7;  // Capacitive touch input for on/off
const uint8_t switchUp = T8;   // Capacitive touch input for increasing brightness
const uint8_t switchDn = T9;   // Capacitive touch input for decreasing brightness
const uint8_t tempUp = T10;    // Capacitive touch input for increasing cool color
const uint8_t tempDn = T11;    // Capacitive touch input for increasing warm color
const uint8_t dimOut1 = 36;    // Cool white channel (PWM pin)
const uint8_t dimOut2 = 35;    // Warm white channel (PWM pin)
const uint8_t ws2812Pin = 40;  // WS2812 data pin

const uint8_t MAX_BRIGHTNESS = 95;   


bool ignoreRepeats = true;
uint32_t startTime = 0;

// Add state variables for press-and-hold and double-tap detection
bool lastSwitchUpState = false;
bool lastSwitchDnState = false;
bool lastTempUpState = false;
bool lastTempDnState = false;

unsigned long lastTapTimeUp = 0;
unsigned long lastTapTimeDown = 0;
unsigned long lastTapTimeTempUp = 0;
unsigned long lastTapTimeTempDown = 0;

const unsigned long doubleTapInterval = 300;  // Max time for a double-tap in milliseconds
const unsigned long dimholdDelay = 10;        // Time to wait before considering a hold
const unsigned long tempholdDelay = 10;

unsigned long switchUpHoldStart = 0;
unsigned long switchDnHoldStart = 0;
unsigned long tempUpHoldStart = 0;
unsigned long tempDnHoldStart = 0;

// WS2812 LED Configuration
const uint16_t numPixels = 1;  // Number of WS2812 LEDs
Adafruit_NeoPixel ws2812 = Adafruit_NeoPixel(numPixels, ws2812Pin, NEO_GRB + NEO_KHZ800);

// Constants and Variables
const float gammaValue = 2.2;
const int step = 1;
int brightness = 50;
float tempRatio = 0.5;
unsigned long lastTempChange = 0;
const unsigned long tempDelay = 10;
unsigned long lastBrightnessChange = 0;
const unsigned long brightnessDelay = 10;
unsigned long lastColorChange = 0;
const unsigned long colorDelay = 500;  // Time between WS2812 color changes
uint8_t colorIndex = 0;
bool ledState = false;            // LED on/off state
bool lastLedSwitchState = false;  // on/off switch state
bool ledSwitchState = 0;
bool switchUpState = 0;
bool switchDnState = 0;
bool tempUpState = 0;
bool tempDnState = 0;

// Filtered touch values
float filteredLedSwitch = 0;
float filteredTouchUp = 0;
float filteredTouchDown = 0;
float filteredTouchTempUp = 0;
float filteredTouchTempDown = 0;

// Constants for restart check
const int maxRepeatedReads = 10;      // Number of consecutive same values before restarting
uint16_t previousLedSwitchValue = 0;  // To store the previous touchRead value
int repeatedCount = 0;                // Counter for consecutive repeated values

// PWM Configuration
const uint32_t pwmFrequency = 20000;
const uint8_t pwmResolution = 10;
const uint32_t pwmMaxDuty = (1 << pwmResolution) - 1;

// LEDC Channels
const ledc_channel_t coolChannel = LEDC_CHANNEL_0;
const ledc_channel_t warmChannel = LEDC_CHANNEL_1;


// Define the pin for the ALS-PT19-315C sensor
const int lightSensorPin = 5; // GPIO5 for the light sensor
const float resistorValue = 10000.0; // 10 kΩ resistor in the voltage divider
//const unsigned long lightReadInterval = 10000; // 10 seconds interval
//unsigned long lastLightReadTime = 0;


void readAmbientLight() {
  // Read the ADC value
  int adcValue = analogRead(lightSensorPin);

  // Calculate voltage (assuming 12-bit ADC and 3.3V reference voltage)
  float voltage = (adcValue / 4095.0) * 3.3;

  // Calculate photocurrent (Iph in microamps)
  float Iph = (voltage / resistorValue) * 1e6; // Convert to microamps

  // Calculate illuminance (lux) using typical sensitivity of 100 µA at 1000 lux
  float illuminance = (Iph / 100.0) * 1000.0;

  // Print the results
  Serial.print("Raw ADC Value: ");
  Serial.println(adcValue);
  Serial.print("Sensor Voltage: ");
  Serial.println(voltage, 3);
  Serial.print("Photocurrent (µA): ");
  Serial.println(Iph, 2);
  Serial.print("Illuminance (lux): ");
  Serial.println(illuminance, 2);
}


// Constants for NTC and ADC
const int adcPin = 16;                  // GPIO16 for ADC
const float adcMaxValue = 4095.0;       // 12-bit ADC resolution
const float vRef = 3.3;                 // Reference voltage
const float seriesResistor = 10000;     // 10kΩ series resistor
const float nominalResistance = 10000;  // 10kΩ at 25°C
const float nominalTemperature = 25.0;  // Nominal temperature in °C
const float bCoefficient = 3434;        // B-coefficient of the thermistor

unsigned long lastSensorReadTime = 0;            // Tracks the last time temperature was read
const unsigned long sensorReadInterval = 10000;  // Interval to read temperature (10 seconds)

float readTemperature() {
  // Read the ADC value
  int adcValue = analogRead(adcPin);

  // Avoid divide by zero errors
  if (adcValue == 0 || adcValue == adcMaxValue) {
    Serial.println("ADC value is invalid.");
    return NAN;  // Return 'Not a Number' to indicate error
  }

  // Calculate the voltage across the thermistor
  float voltage = (adcValue / adcMaxValue) * vRef;

  // Calculate the resistance of the thermistor
  float thermistorResistance = seriesResistor * (voltage / (vRef - voltage));

  // Ensure the resistance is valid
  if (thermistorResistance <= 0) {
    Serial.println("Calculated resistance is invalid.");
    return NAN;
  }

  // Apply the Steinhart-Hart equation to calculate the temperature
  float steinhart;
  steinhart = thermistorResistance / nominalResistance;  // (R/Ro)
  steinhart = log(steinhart);                            // ln(R/Ro)
  steinhart /= bCoefficient;                             // 1/B * ln(R/Ro) using B=3434K
  steinhart += 1.0 / (nominalTemperature + 273.15);      // + (1/To)
  steinhart = 1.0 / steinhart;                           // Invert
  steinhart -= 273.15;                                   // Convert to °C


  Serial.print("ADC Value: ");
  Serial.println(adcValue);
  Serial.print("Voltage: ");
  Serial.println(voltage, 3);
  Serial.print("Thermistor Resistance: ");
  Serial.println(thermistorResistance, 2);
  Serial.print("Calculated Temperature: ");
  Serial.println(steinhart, 2);

  return steinhart;
}
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

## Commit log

2022-05-21 Added printed parts
    [Base.step, Base.stl, Belt Clip.step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]
2022-07-05 Brightness control script (for Trinket M0)
    Added python script for LED brightness control
2022-07-05 Added new models for printed parts
    Added STL and STEP files for the lighting assembly mount
    [Lighting Assembly Mount.step, Lighting Assembly Mount.stl]
2022-07-10 Added (working) parts list
    [working parts list.xlsx]
2022-07-10 Swapped parts list excel sheet for csv
    [working parts list.csv, working parts list.xlsx]
2022-07-10 Added c-clamp to parts list
    [working parts list.csv]
2022-07-10 Updated parts list
    Sorted by category
    Fixed vertical rail link
    [working parts list.csv]
2022-08-10 LED Cover, carriage update, and 20x20 vertical rail
    Added a V1 cover design for the LED assembly
    Streamlined the carriage to remove excess material
    Reverted back to the 20x20mm vertical rail with an updated counterweight
    [Base.step, Base.stl, Carriage.step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]
2022-08-18 Updated links in parts list
    [working parts list.csv]
2022-09-27 Update working parts list.csv
    [working parts list.csv]
2022-10-18 Added cable drag chain
    - Updated carriage to allow mounting of drag chain
    - Modified belt clip for easier CNC routing of carriage
    - Added special "routed spacer" to replace on aluminum spacer on the carriage (necessary for cable routing between drag chains)
    [Belt Clip.step, Belt Clip.stl, Carriage.step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]
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2023-01-04 Update working parts list.csv
    Added some links to european/aliexpress supplier for the linked parts which are in stock at the moment. I tried to use as few different suppliers as possible.
    [working parts list.csv]
2023-01-05 Build log #7 changes
    Parts and code updates to reflect Build log #7 updates
    [Base.step, Base.stl, Brightness Button Socket.stl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]
2023-01-05 Create Drag Chain (16 links, print-in-place).stl
    Added print-in-place drag chain with 16 links
    [Drag Chain (16 links, print-in-place).stl]
2023-01-05 Update working parts list.csv
    Added:
    - Updated LED (see buildlog #7)
    - LED housing (for compatibility with new LED)
    - LED power supply (for compatibility with new LED)
    - QT PY SAMD21 (see buildlog #7)
    - MPM3610 5V Buck Converter (see buildlog #7)
    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
    [working parts list.csv]
2023-01-05 Update working parts list.csv
    Add quotation marks to notes
    [working parts list.csv]
2023-01-06 Update working parts list.csv
    Replaced EU source for super low profile m5 lock nuts (the ones listed weren't locking)
    [working parts list.csv]
2023-01-11 Update working parts list.csv
    Fixed linear rail length (was 250mm, should be 500)
    Added pogo pins
    [working parts list.csv]
2023-01-15 Update working parts list.csv
    Updated vertical rail from 20x40 to 20x20
    [working parts list.csv]
2023-01-30 Added DIYson Express Directory and project files
    I've added a variant of the DIYson called the DIYson Express. It's a more approachable alternative to the project that allows you to build a simplified DIYson without the ever-increasing skill and co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
    - All STLs have been added to the subdirectory
    - Added a Fusion 360 template to help with making your own LED holders
    - Added a full parts list specifically for the Express
    [Base.step, Base.stl, Belt Clip.step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]
2023-01-31 Added DIYson Express STEP Files
    [Base.step, Carriage Belt Clip.step, Carriage.step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]
2023-02-01 Create express logo expanded.dxf
    Added DIYson Express logo dxf file
    [express logo expanded.dxf]
2023-02-01 Update parts list.csv
    Changed screws used to fasten carriage belt clip from M2x6mm to M2x4mm
    [parts list.csv]
2023-02-02 Add 6mm to eccentric spacer
    [parts list.csv]
2023-02-05 Update parts list.csv
    Replaced discontinued magents
    [parts list.csv]
2023-02-05 Fixed magnet link
    [parts list.csv]
2023-02-06 Updated M5 lock nuts in parts list
    Updated with some shorter and less expensive M5 lock nuts for the carriage (also they are currently in stock which is nice)
    [parts list.csv]
2023-02-09 Create print_guide.md
    This is a first pass at a print guide. It's rough but hopefully gives folks a good starting point.
2023-02-10 Update LED Control.py
    Updated sleep duration in fadeBetween (was 10x too slow)
    Restored lost line initially setting pwm to 0 which allows the LED to fully power off while power = false (I had deleted accidentally)
2023-02-14 Updated counterweight design
    [Counterweight - Lid.step, Counterweight - Lid.stl, Counterweight Belt Clip.step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]
2023-02-14 Pulley mount tweak
    Optimized pulley mount a bit to reduce interference with the belt
    [Pulley Mount.step, Pulley Mount.stl]
2023-02-17 Create Base.f3d
    Added Fusion 360 file for base for @dflemstr and @legopc
    [Base.f3d]
2023-02-22 Update print_guide.md
    Correct titles to reflect printed items.
2023-02-22 Create Desk Mount.f3d
    [Desk Mount.f3d]
2023-03-04 Added dir + needed Parts
    [Added Parts.csv]
2023-03-04 Add removed Parts
    [Removed Parts.csv]
2023-03-05 Added new base files
    Base.f3d --> names are in german. Added to change tolerances (if needed)
    [Base.f3d, Base.step]
2023-03-06 Express hardware booster kit updates
    Added Express README with link to hardware booster kit
    Added column in DIYson Express parts list to indicate whether a part is included in the hardware booster kit
    [parts list.csv]
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2023-05-02 Add the gimbal alternative for the DIYson Express
    [Extrusion bracket.stl, Inner ring.stl, Outer ring.stl]
2023-09-02 Renamed community mods directory
    [Extrusion bracket.stl, Inner ring.stl, Outer ring.stl]
2023-10-19 Renamed community alternatives directory
    [Added Parts.csv, Base.f3d, Base.step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]
2023-11-11 Update working parts list.csv
    Added note about lens fragility
    [working parts list.csv]
2023-12-24 Update working parts list.csv
    Changed source for led control pogo pins from digikey to mouser (issue #46) thanks @hornej
    [working parts list.csv]
2024-01-25 Add LED Holder for LumeCube
    [LEDHolderLumeCube.step]
2024-04-07 Create circuitpython-start-guide.md
    A reminder for myself and others of how to get a new QT Py up and running with Circuitpython, what libraries are needed, and where to find things
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2024-04-12 Added STL and Readme
    [Lume Cube Bicolor Panel.stl]
2024-06-07 Added new LED driver to parts list
    [working parts list.csv]
2024-12-11 Add alternative base for IRWIN QUICK-GRIP clamps
    [Base for IRWIN QUICK-GRIP.3mf, Base for IRWIN QUICK-GRIP.step]
2025-01-30 add PCB and relevant 3d parts and code
    [Base for IRWIN QUICK-GRIP.3mf, Base for IRWIN QUICK-GRIP.step, Base.step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]
2025-01-30 Update working parts list
    [working parts list.csv]
2026-01-27 add circadian lighting. refine controls
    [Bill of Materials-DIYson.csv]
2026-02-06 esphome capacitive touch kind of working. giving up on it for now
2026-03-15 simplify code and fix ESP-IDF v5.1 build compatibility
    - DRY up duplicated brightness gamma calculation in update_outputs()
    - Remove stale comments, unused variables, and temp file
    - Fix esp_driver_* component names for v5.1 compatibility (use driver)
    - Add ADC_ATTEN_DB_12 compat shim for pre-5.2 ESP-IDF
    - Bump minimum IDF version to >=5.0.0
    [otl_main.c]
2026-03-16 remove outdated working parts list
    [working parts list.csv]
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2026-03-25 feat: add optional apple home homekit integration
    [partitions.csv]
2026-03-25 fix: raise lwip socket limit for homekit
2026-03-25 fix: wait for wifi before starting mqtt
    [otl_mqtt.c]
2026-03-25 fix: classify led ntc temperature as diagnostic
    [otl_mqtt.c]
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2026-03-25 fix: rename esp32 internal temperature sensor
    [otl_main.c, otl_mqtt.c]
2026-03-25 fix: move circadian controls to configuration
    [otl_mqtt.c]
2026-03-26 fix: restore moonlight dim-down hold
    [otl_main.c]
2026-03-31 feat: expand HA diagnostics and radar controls
    Add Home Assistant diagnostics and runtime controls for radar, logging, thermal, and firmware metadata.
    Also fix the HomeKit pairing-timeout reset path and reduce radar presence-on delay for faster wake-up.
    [otl_main.c, otl_mqtt.c]
2026-04-03 add prelim v1.1 led driver files
    [Bill of Materials-DIYson.csv, Bill of Materials-OTL2_LED-Driver.csv]
